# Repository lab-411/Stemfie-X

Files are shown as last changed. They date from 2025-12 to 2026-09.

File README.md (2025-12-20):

# Stemfie-X

STEMFIE-X je konštrukčná stavebnica zameraná na polytechnické vzdelávanie s podporou praktického osvojenia si skúseností z moderných technológií v oblasti návrhu a konštrukcie mechatronických systémov, konštrukčných materiálov, elektroniky, programovania a riadenia.

STEMFIE-X is a construction kit focused on polytechnic education with the support of practical acquisition of experience from modern technologies in the field of design and construction of mechatronic systems, structural materials, electronics, programming and control.

# Kniha / Book

Renderovaná kniha je dostupná na URL

The rendered book is available at URL

https://lab-411.github.io/Stemfie-X/_build/html/index.html

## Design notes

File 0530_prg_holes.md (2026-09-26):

---
jupytext:
  formats: md:myst
  text_representation:
    extension: .md
    format_name: myst
    format_version: 0.13
    jupytext_version: 1.11.5
kernelspec:
  display_name: Python 3
  language: python
  name: python3
---
# <font color='navy'> Montážne otvory  </font>

```{figure} ./img/banner.png
:width: 800px
:name: holes_201
```

Pre vytváranie montážnych dier, štrbín a drážok je v *Stemfie-X* vytvorená trieda *Hole*. Táto generuje pomocné objekty, ktoré sú potom od vopred vytvorených dielov odčítané pomocou logickéj operácie *Difference* `D()`. Štrbinu využívame aj pri konštrukciách, kde pri dieloch pod uhlom sa montážny otvor nenachádza v rastri **BU**. Princíp tvorby otvorov je zrejmý z nasledujúceho obrázku.

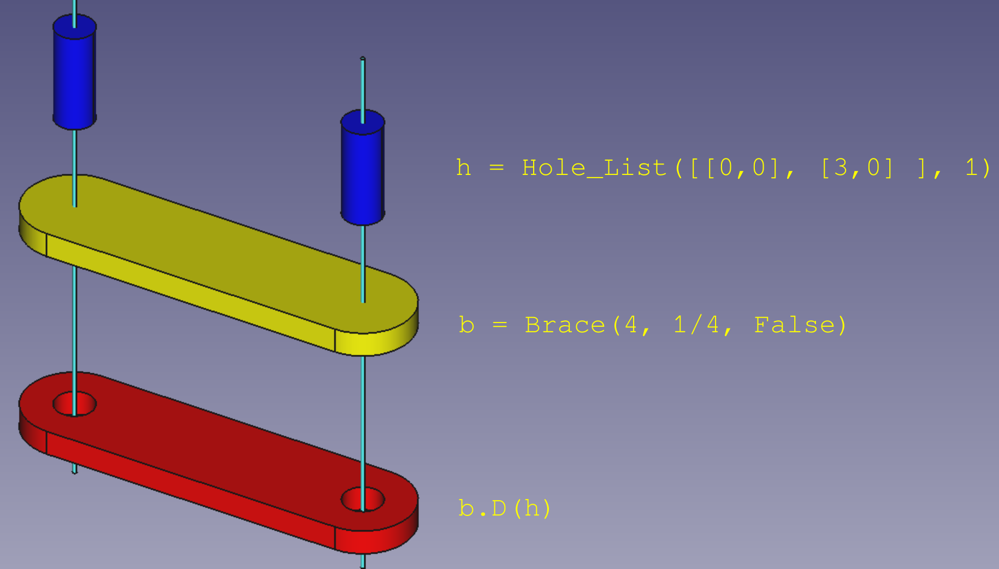
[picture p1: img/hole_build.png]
```{figure} ./img/hole_build.png
:width: 500px
:name: holes_202

Postup vytvárania otvorov v dieloch,
```

## <font color='purple'> Knižnica </font>

    Hole(length)
    Hole_List(hole_list, length)
    Hole_Grid(dim_x, dim_y, length, offs_x, offs_y, offs_z)
    Hole_Slot(size, height, center)
    
    Parametre       Default   Popis 
    --------------------------------------------------------------
    length          1         dĺžka diery v BU
    hole_list                 zoznam pozícií dier v BU [[x1,y1], [x2,y2] ... ]
    dim_x, dim_y              rozmery pola dier v BU
    offs_x          1         posun pola dier v smere osi X v BU 
    offs_y          1         posun pola dier v smere osi Y v BU 
    offs_z          1         posun pola dier v smere osi Z v BU 
    size                      dĺžka štrbiny v BU
    height          1/4       výška štrbiny v BU
    center          False     umiestnenie štrbiny v strede sur. sustavy
            
### <font color='brown'> Príklady použitia </font>

```{code-block} Python
:caption: Jednoduchá spojka so štrbinou
from lib import *
bs = Brace(5, holes=False)          # brace without holes
hh = Hole_Slot(3)                   # slot
hs = Hole_List([ [3,0], [4,0]] )    # holes
bs.D([hh, hs])                      # difference 
```

```{code-cell} ipython3  
:tags: ["remove-cell"]
from lib import *
                                    # Brace with slot and holes
bs = Brace(5, holes=False)          # brace without holes
hh = Hole_Slot(3)                   # slot
hs = Hole_List([ [3,0], [4,0]] )    # holes
bs.D([hh, hs])                      # difference 
convert_to_image(bs, './src/0520a')
```

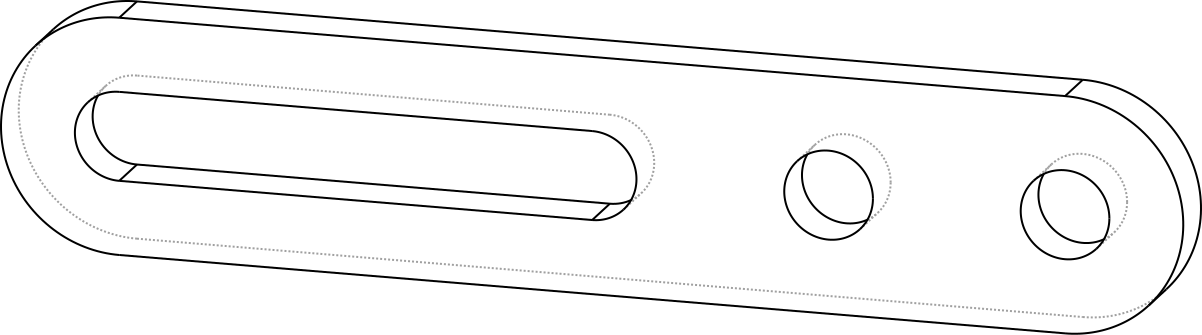
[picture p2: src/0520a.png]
```{figure} ./src/0520a.png
:width: 200px

jednoduchá spojka so štrbinou
```

```{code-block} Python
:caption: Použitie poľa otvorov
from lib import *
c = BU_Cube([4,4,1/4], False)
h = Hole_Grid( 4,2 , 1, 1/2, 1/2)
c.D(h)
```

```{code-cell} ipython3 
:tags: ["remove-cell"]
from lib import *
c = BU_Cube([4,4,1/4], False)
h = Hole_Grid( 4,2 , 1, 1/2, 1/2)
c.D(h)
convert_to_image(c, './src/0520c')
```

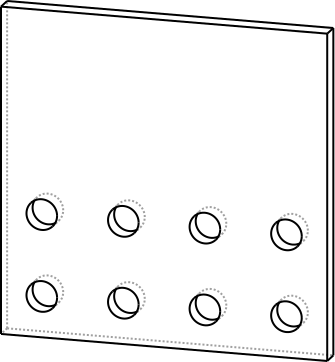
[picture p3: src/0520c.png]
```{figure} ./src/0520c.png
:width: 150px
Blok s otvormi.
```

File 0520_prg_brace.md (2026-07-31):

---
jupytext:
  formats: md:myst
  text_representation:
    extension: .md
    format_name: myst
    format_version: 0.13
    jupytext_version: 1.11.5
kernelspec:
  display_name: Python 3
  language: python
  name: python3
---

# <font color='navy'>  Spojky  </font>

```{figure} ./img/banner.png
:width: 800px
:name: stmx_112
```

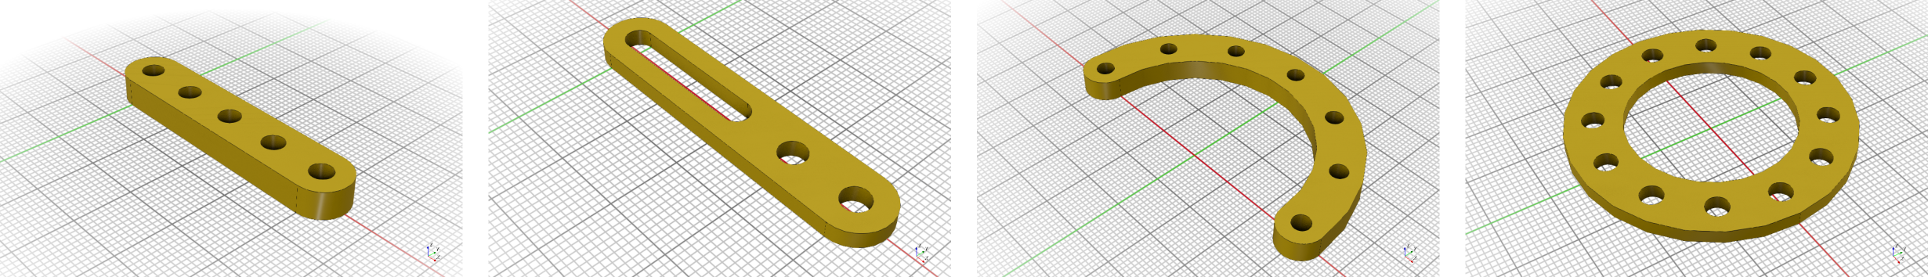
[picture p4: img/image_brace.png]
```{figure} ./img/image_brace.png
:width: 800px
:name: stmx_110

```

**Spojky** (Brace) sú základným konštrukčným typom dielov v *Stemfie-X* primárne určený pre spájanie dielov, ale je možné ich využiť aj ako konštrukčný prvok na vytváranie vystužených konštrukcií ako sú ramená žeriavov, robotov a pod. Spojky môžu obsahovať montážne otvory ako aj štrbiny. Štandardná hrúbka spojky je 1/4 **BU** (2.5mm), pomocou knižnice je možné programovo vytvárať spojky rôznych tvarov a konfigurácií. Lineárna spojka je rozmerovo kompatibilná s kovovými spojkami stavebníc *Meccano* a *Merkur* so vzdialenosťami montážnych otvorov 10mm. 

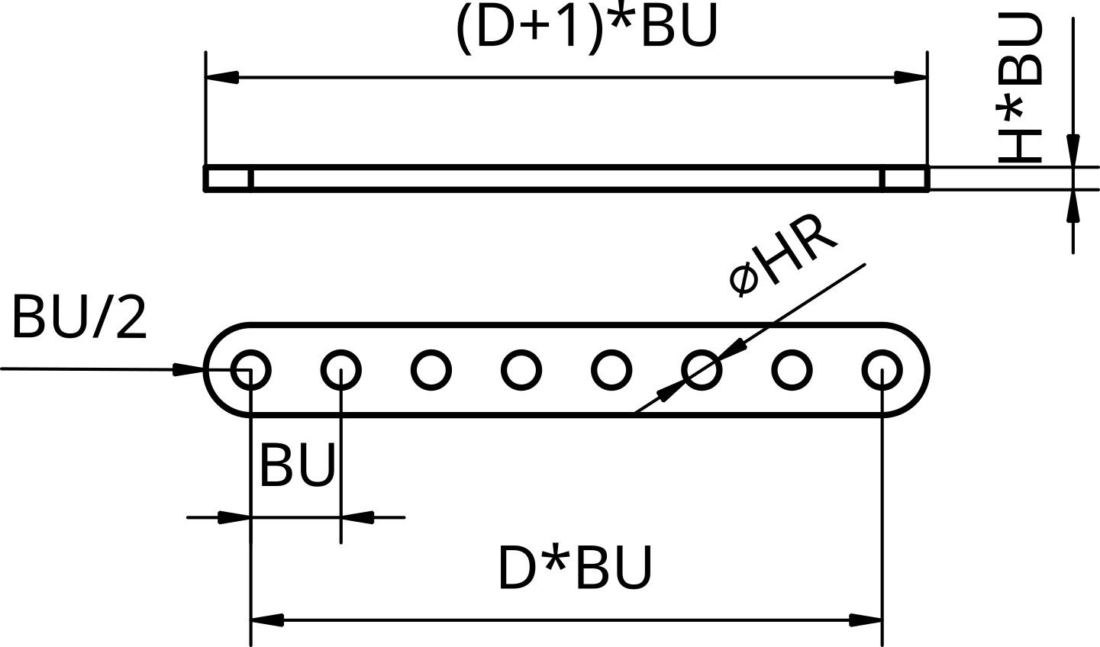
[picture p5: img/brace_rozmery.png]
```{figure} ./img/brace_rozmery.png
:width: 400px

Základné parametre spojky (spojka, D=8, H=1/4).
```

## <font color='purple'> Knižnica </font>

Pomocou knižnice môžeme vytvárať záladné typy spojok a pomocou logických operácií aj odvodené modifikácie. Základným typom je lineárna spojka *Brace*, oblúková spojka *Brace_Arc*, kruhová spojka *Brace_Circle* a rozšírená spjka *Brace_Plate*. Funkcie pre generovanie spojok majú formát:

    Brace(size, height, holes, center, hole_rad)
    Brace_Arc(radius, angle, height, num_holes, center, hole_rad)
    Brace_Circle(radius, height, num_holes, center, hole_rad)
    Brace_Plate(x, y,  height, holes, center, hole_rad)
    
    Parametre       Default   Popis 
    --------------------------------------------------------------
    size            1         rozmery v počte otvorov 
    height          1         výška
    length          1         dĺžka 
    radius          5         polomer
    holes           True      lineárna spojka / platňa s otvormi / bez otvorov
    num_holes       4         počet montážnych otvorov
    angle           180       uhol v stupňoch
    center          True      poloha v strede súradnicovej sústavy
    x               3         rozmer v smere osi X
    y               3         rozmer v smere osi Y
    hole_rad        HR_BASE   polomer všetkých otvorov (HR_BASE, HR_AXIS) alebo v BU

### <font color='brown'> Značenie dielov </font>

Pre prehľadnejšie označovanie spojok v zoznamoch dielov a katalógoch je vhodné tieto označovať kódmi, ktoré označujú ich parametre. Mená štandardných spojok sú generované automaticky pri ich vytváraní.

    brace_t_dd_hh_pp_ss[s]    basic form
    brace_t_dd_hh_pp          abbreviated forms, unlisted parameters have default values
    brace_t_dd_hh
    brace_t_dd

    t  - brace type                         dd - brace size               hh - brace height
         B - simple brace                        01 ... 99 BU                  01 =    1 BU
         C - circle brace                                                      ...
         A - arc brace                                                         10 =   10 BU
         P - brace plate                                                       12 =  1/2 BU
         X - user defined non standard brace                                   14 =  1/4 BU 

    ss - number of slots                    pp - number of holes if it does not match the size
         00 ... 99                               00 ... 99

    brace_B_dd_hh_pp_ss
        dd - brace size
        pp - number of holes
        ss - number of slots 
        
    brace_C_dd_hh_pp_ss
        dd - brace radius
        hh - brace height     
        pp - number of holes
        ss - number of slots (TODO, not implemented)

    brace_A_dd_hh_pp_sss
        dd  - brace radius
        hh  - brace height, default value is 1/4 BU      
        pp  - number of holes
        sss - brace angle in [deg] 001 ... 180
        
    brace_P_xx_yy_hh
        xx  - brace plate x size
        yy  - brace plate y size
        hh  - brace plate height, default value is 1/4 BU 

## <font color='purple'>  Príklady použitia </font>

### <font color='brown'> Jednoduchá spojka </font>

Pre vygenerovanie jednoduchej spojky o štandardnej hrúbke **1/4 BU** je postačujúce zadať jej rozmer v **BU** jednotkách.

```{code-block} Python
:caption: Vytvorenie jednoduchej spojky
from lib import *
b1 = Brace(5)               # brace_B_05_14
b1.export_step(b1.name)     # export spojky vo formate step  
```

```{code-cell} ipython3  
:tags: ["remove-cell"]

from lib import *
from lib.utils import *

b1 = Brace(5)    # brace_B_05
convert_to_image(b1, './src/brace_b1')
```

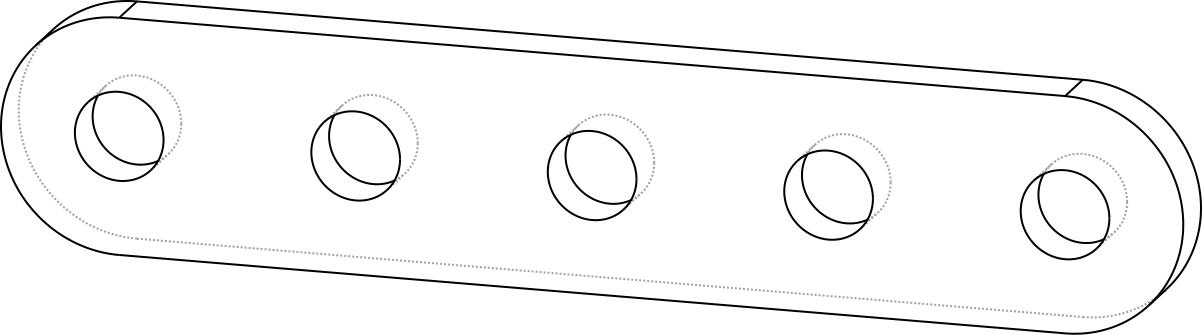
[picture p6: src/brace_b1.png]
```{figure} ./src/brace_b1.png
:width: 200px

Jednoducha spojka
```

### <font color='brown'> Spojka so štrbinami </font>

Štrbiny požadovanej dĺžky vytvoríme pomocou triedy **Hole_Slot**, posunieme ich pomocou operátora **BU_Tx** do požadovanej pozície a pomocou operátora **D()** odpočítame od štandardnej spojky.

```{code-block} Python
:caption: Vytvorenie spojky so štrbinami
from lib import *
b2 = Brace(17)              # standardna spojka
h1 = Hole_Slot(2).BU_Tx(4)  # strbina a jej posun dpo vzdialenosti BU=4
h2 = h1.copy().BU_Tx(7)     # kopia strbiny a posun o dalsich 7 BU

b2.D([h1, h2])              # odpocitanie strbin od zakladnej spojky
                            # export spojky - dlzka 17 otvorov, hrubka 1/4 BU, 
                            #                 13 otvorov, 2 strbiny 
b2.export_step('brace_B_17_14_13_02')
```

```{code-cell} ipython3  
:tags: ["remove-cell"]
from lib import *
from lib.utils import *
       
b2 = Brace(17)              # standardna spojka
h1 = Hole_Slot(2).BU_Tx(4)  # strbina a jej posun dpo vzdialenosti BU=4
h2 = h1.copy().BU_Tx(7)     # kopia strbiny a posun o dalsich 7 BU

b2.D([h1, h2])              # odpocitanie strbin od zakladnej spojky

convert_to_image(b2, './src/brace_b2')
```

```{figure} ./src/brace_b2.png
:width: 600px

Spojka so štrbinami.
```

### <font color='brown'> Uhlová spojka </font>

Uhlovú spojku vytvoríme operáciou zjednotenia dvoch štandardných spojok.

```{code-block} Python
:caption: Vytvorenie uhlovej spojky
from lib import *
b3 = Brace(4)               # standardna spojka
b4 = Brace(3).Rz()          # spojka otocena o 90 stupnov
b3.U(b4)                    # zjednotenie
                            # export uzivatelsky definovanej spojky
b3.export_step('brace_X_03_04_14')
```

```{code-cell} ipython3  
:tags: ["remove-cell"]
from lib import *
from lib.utils import *
       
b3 = Brace(4)               # standardna spojka
b4 = Brace(3).Rz()          # spojka otocena o 90 stupnov
b3.U(b4)                    # zjednotenie
                            # export uzivatelsky definovanej spojky
                        
convert_to_image(b3, './src/brace_b3')
```

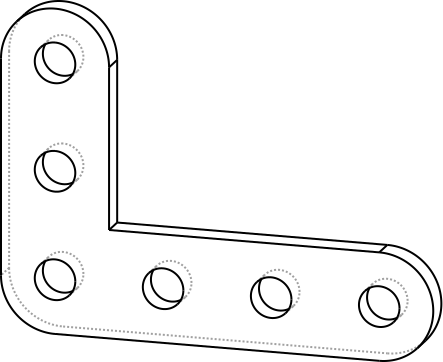
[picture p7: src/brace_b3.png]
```{figure} ./src/brace_b3.png
:width: 160px

Uživateľsky definovaná uhlová spojka.
```

### <font color='brown'> Oblúková spojka s tetivou </font>

Pri oblúkovej spojke musí mať tetiva oblúku veľkosť v násobkoch **BU**. Pre výpočet parametrov oblúkovej spojky zadáme dĺžku tetivy a polomer oblúka, napríklad

* radius = 4 BU
* brace length = 7 BU

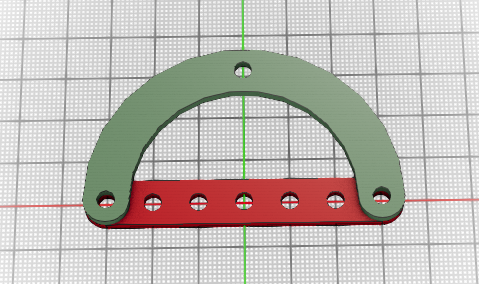
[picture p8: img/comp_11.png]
```{figure} ./img/comp_11.png
:width: 400px

Oblúková a lineárna spojka
```

Z uvedených parametrov musíme pre konštrukciu spojky výpočítať uhol a offsetu voči stredu opísanej kružnice podľa obrázku

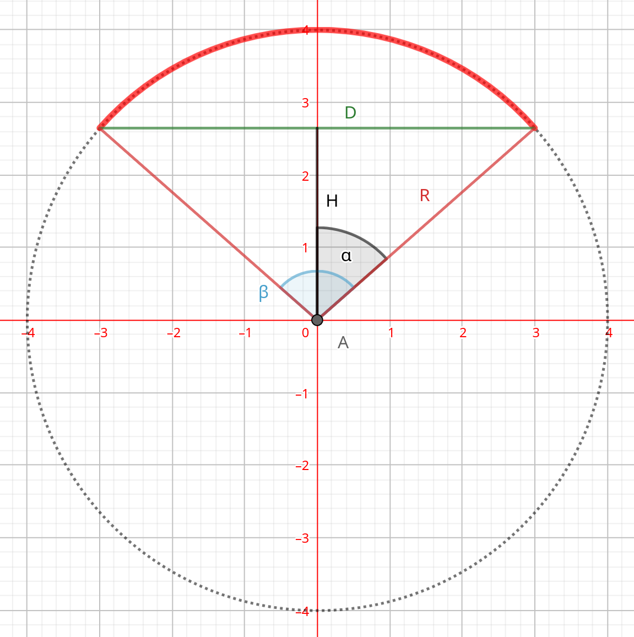
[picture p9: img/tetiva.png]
```{figure} ./img/tetiva.png
:width: 350px

Veličiny pre výpočet oblúkovej spojky
```

Vstupnými hodnotami pre výpočet sú

* $R$    - circle radius, in BU units
* $D$    - chord length in BU units, D >= 2*R+1

Výstupnými hodnotami sú 

* $\beta$ - calculated angle
* $H$    - calculated offset

$$
\begin{align*}
\beta &= 2 \alpha      \\
\frac{D-1}{2} &= R \cdot \sin(\alpha)    \\
\\
\beta &= 2 \alpha = 2 \cdot \arcsin \Big( \frac{D}{2R} \Big) \\
H &= R \cdot cos(\alpha) \\
\end{align*}
$$

Konštrukcia oblúkovej spojky na základe výpočtu

    from numpy import arcsin, pi

    R = 3   # arc radius
    D = 7   # D >= 2*R+1 
    N = 3   # pocet otvorov
    
    alpha = arcsin( (D-1) / (2*R ) )
    beta = 2*alpha/pi*180
    H = R*cos(alpha)

    b3 = Brace_Arc(R, bdeg, 1/4, N, center=True).Rz(90-bdeg/2).BU_T([0, -H, 0])
    b4 = Brace(D, center=True).BU_Tz(-1/2)

```{code-cell} ipython3  
:tags: ["remove-cell"]
from lib import *
from lib.utils import *
from numpy import arcsin, pi

D = 7   # D >= 2*R+1  
R = 3   # arc radius

alpha = arcsin( (D-1) / (2*R ) )
beta = 2*alpha/pi*180
H = R*cos(alpha)

b5 = Brace_Arc(R, beta, 1/4, 3, center=True).Rz(90-beta/2).BU_T([0, -H, 0])
b6 = Brace(D, center=True)  #.BU_Tz(-1/2)

b5.U(b6)
convert_to_image(b5, './src/brace_b5')
```

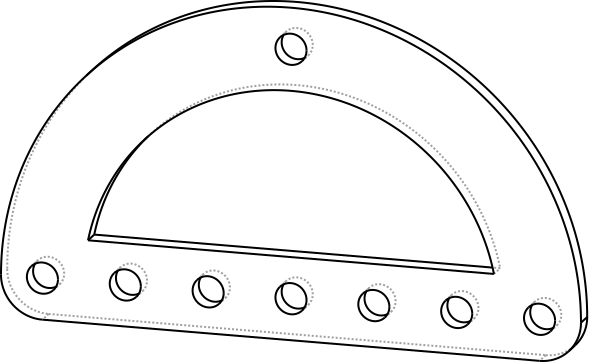
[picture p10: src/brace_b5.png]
```{figure} ./src/brace_b5.png
:width: 250px

Oblukova spojka s tetivou.
```

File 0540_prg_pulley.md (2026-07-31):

---
jupytext:
  formats: md:myst
  text_representation:
    extension: .md
    format_name: myst
    format_version: 0.13
    jupytext_version: 1.11.5
kernelspec:
  display_name: Python 3
  language: python
  name: python3
---
# <font color='navy'>  Kladky  </font>

```{figure} ./img/banner.png
:width: 800px
:name: stmx_112
```

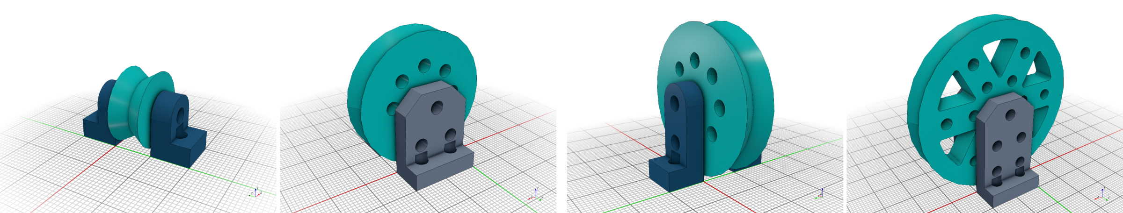
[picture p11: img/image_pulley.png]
```{figure} ./img/image_pulley.png
:width: 800px
:name: stmx_110

```

Kladky sú konštrukčnými prvkami pre tvorbu jednoduchých strojov (jednoduchá kladka, kladkostroj) a lanových prevodov.  

## <font color='purple'> Knižnica </font>

Knižnica obsahuje základné veľkosti kladiek a držiakov.

    Pulley_A(diam, thick, dp)
    Pulley_B(diam, thick, dp, dh, rh)
    Pulley_C(diam, thick, dp, dh, rh)
    
    Parametre       Default   Popis 
    --------------------------------------------------------------
    diam                      priemer kladky
    thick           1         hrubka kladky
    dp              1/2       zahlbenie kladky (vnutorny priemer)
    dh              1/4       hrubka nosnej vyplne kladky
    rh              [1]       pole priemerov otvorov
    
    Pulley_Holder_A(height)   držiak o šírke 1BU
    Pulley_Holder_B(height)   držiak o šírke 2BU

### <font color='brown'>  Značenie dielov </font>

    pulley_t_dd_hh

    t  - typ kladky
         A - jednoduchá plná kladka pre menšie priemery 
         B - odľahčená kladka pre väčšie priemery
         C - odľahčená kladka s lúčmi pre veľke priemery
    
    dd - priemer hladky
    hh - hrubka kladky
    
    pulhold_t_nn
    
    t  - typ držiaka
    hh - výška držiaka
    
## <font color='purple'> Príklady použitia </font>

    p0 = Pulley_A(2,1)        # pulley_A_02_01

```{code-cell} ipython3  
:tags: ["remove-cell"]

from lib import *
from lib.utils import *

p0 = Pulley_A(2,1)
convert_to_image(p0, './src/img_0540a')
```

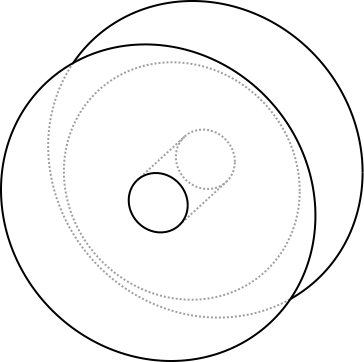
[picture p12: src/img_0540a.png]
```{figure} ./src/img_0540a.png
:width: 110px

Jednoducha plná kladka
```

    p1 = Pulley_B(3,1)        # pulley_B_03_01

```{code-cell} ipython3  
:tags: ["remove-cell"]

from lib import *
from lib.utils import *

p1 = Pulley_B(3,1)
convert_to_image(p1, './src/img_0540b')
```

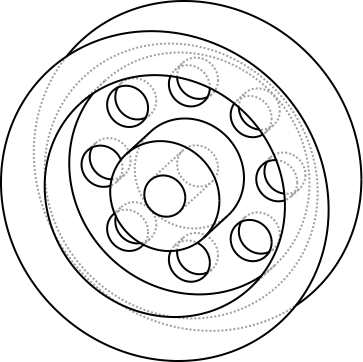
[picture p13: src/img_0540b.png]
```{figure} ./src/img_0540b.png
:width: 160px

Odľahčená kladka
```

    p1 = Pulley_B(3,1)        # pulley_B_03_01

```{code-cell} ipython3  
:tags: ["remove-cell"]

from lib import *
from lib.utils import *

p2 = Pulley_C(4,1)
convert_to_image(p2, './src/img_0540c')
```

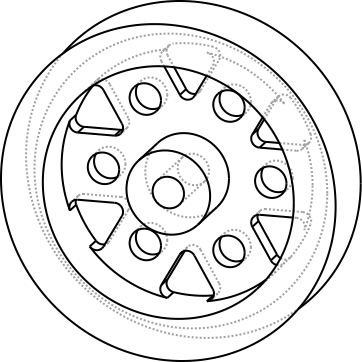
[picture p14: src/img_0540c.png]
```{figure} ./src/img_0540c.png
:width: 180px

Odľahčená veľká kladka
```

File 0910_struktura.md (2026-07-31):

---
jupytext:
  formats: md:myst
  text_representation:
    extension: .md
    format_name: myst
    format_version: 0.13
    jupytext_version: 1.11.5
kernelspec:
  display_name: Python 3
  language: python
  name: python3
---
# <font color='navy'>  Štruktúra knižnice  </font>

Knižnica je tvorená hierarchiou tried odvodenej z knižnica *CadQuery*. Pre tvorbu špeciálnych komponentov je možné triedy knižnice rozšírovať dedením a pridávaním ďalších špecifických vlastností. Štruktúru knižnice *Stemfie-X* zobrazuje nasledujúci diagram

```{code-cell} ipython3  
:tags: ["remove-cell"]

s = r'''
@startuml
hide footbox
scale 2

class Assembly #Khaki
class Workplane #Khaki

Assembly  --o Construct
Construct -> "Stemfie-X"
Workplane --o "Stemfie-X"  

"Stemfie-X" <|-- "Beam_Block"
"Stemfie-X" <|--- "Braces"
"Stemfie-X" <|--- "Holes"
"Stemfie-X" <|---- "BU_Components"

"BU_Components" <|-- "BU_Cube"
"BU_Components" <|-- "BU_Cylinder"
"BU_Components" <|-- "BU_Polyline"
"BU_Components" <|-- "BU_Bar"

"Holes" <|-- "Hole"
"Holes" <|-- "Hole_List"
"Holes" <|-- "Hole_Grid"
"Holes" <|-- "Hole_Slot"

"Braces" <|-- "Brace"
"Braces" <|-- "Brace_Arc"
"Braces" <|-- "Brace_Circle"

class "Stemfie-X" {
BU 
HR
self.obj
BU_Tx() BU_Tx() BU_Tz()
BU_Txy() BU_T() T()
Rx() Ry() Rz() 
Mx() Mx() Mz()
MKx() MKy() MKz() 
D()
U()
I()
copy()
}

class "Construct" {
self.name
self.obj
}

class Holes{
self.length
}

@enduml
'''

fp = open('./jar/prg_101.pnl', 'w')
fp.write(s)
fp.close()

import os
_ = os.system("java -jar ./jar/plantuml.jar ./jar/prg_101.pnl") 

```

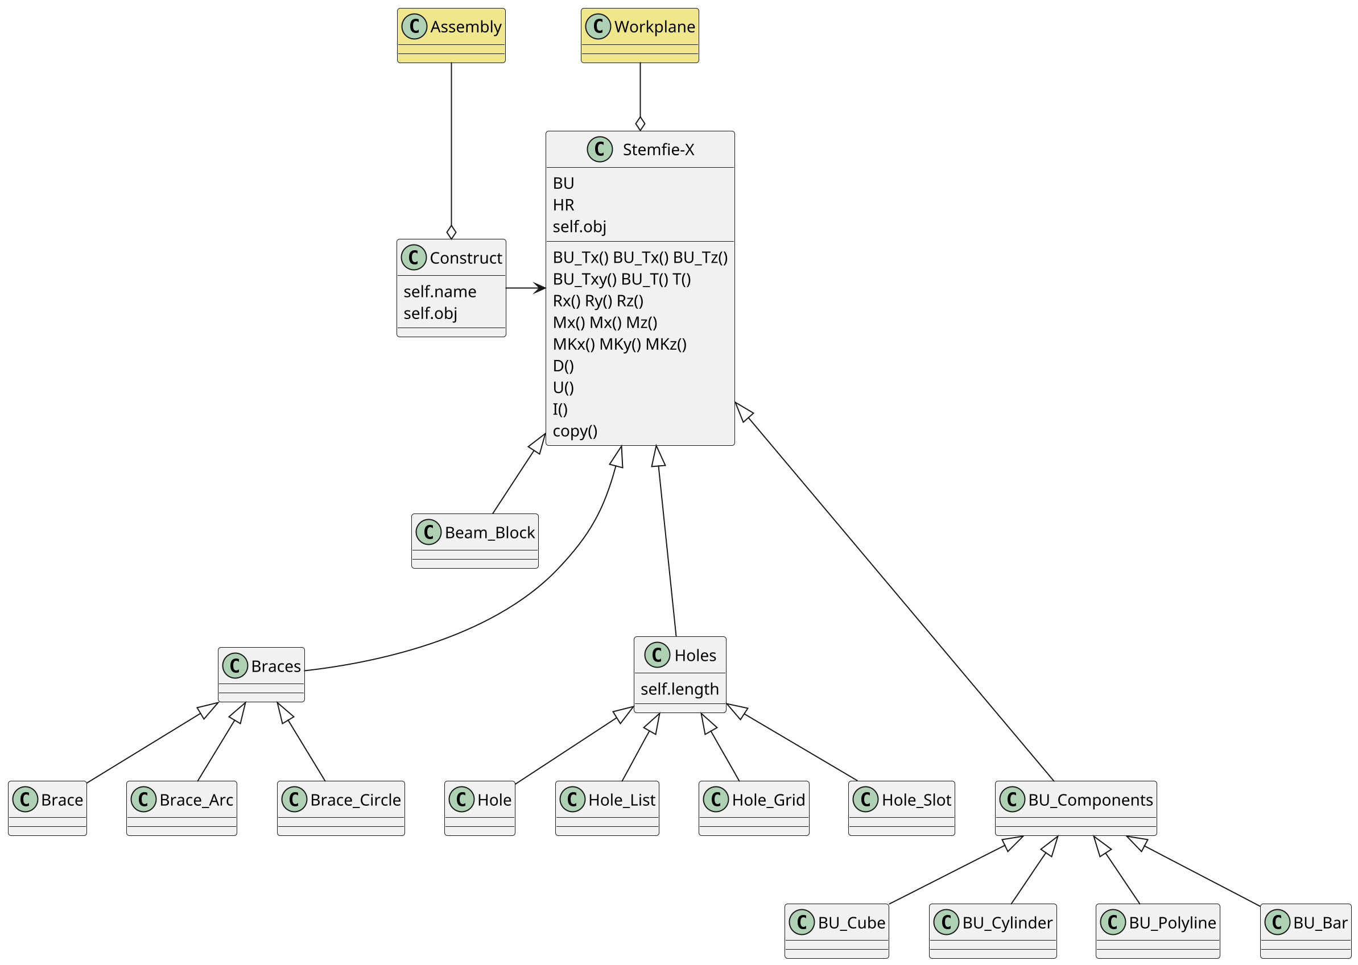
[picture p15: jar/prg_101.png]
```{figure} ./jar/prg_101.png
:width: 800px
:name: stm_0102

Štruktúra tried knižnice Stemfie-X 
```

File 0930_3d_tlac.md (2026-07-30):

---
jupytext:
  formats: md:myst
  text_representation:
    extension: .md
    format_name: myst
    format_version: 0.13
    jupytext_version: 1.11.5
kernelspec:
  display_name: Python 3
  language: python
  name: python3
---

# <font color='navy'> 3D Tlač  </font>

```{figure} ./img/banner.png
:width: 800px
```

## <font color='purple'> Export </font>

## <font color='purple'> Natavenie tlačiarne </font>

Doporučené parametre 3D tlače upravte podľa vašej tlačiarne a použitého materiálu. Diely stavebnice sú v tejto pulikácii generované vo formáte *.step* alebo *.stl*, pre ich tlač použite programové vybavenie doporučované výrobcom tlačiarne. V programe pre prípravu tlače (*slicer*) je vhodné nastaviť parametre tlače

* materiál PLA
* hrúbka vrstvy 0.2mm, bez podpier
* perimeter 4x
* výplň 15%
* teplota materiálu podľa doporučenia výrobcu filamentu, zvyčajne bližšie k hornej udávanej hranici

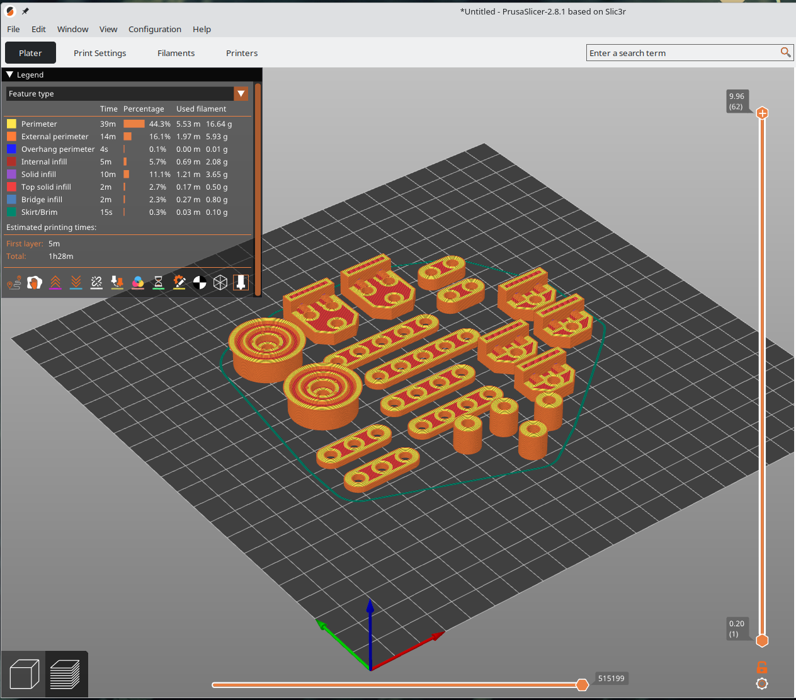
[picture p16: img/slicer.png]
```{figure} ./img/slicer.png
:width: 500px

Príprava tlače dielov stavebnice.
```

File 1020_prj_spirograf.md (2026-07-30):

---
jupytext:
  formats: md:myst
  text_representation:
    extension: .md
    format_name: myst
    format_version: 0.13
    jupytext_version: 1.11.5
kernelspec:
  display_name: Python 3
  language: python
  name: python3
---
# <font color='navy'> Spirograf  </font>

```{figure} ./img/banner.png
:width: 800px
```

```{figure} ./model/1020_spirograf/img/spirograf_demo.jpg
:width: 600px
```

S využitím knižnice pre návrh ozubených kolies možeme programom vytvoriť diely pre jednoduchý spirograf. Návrhom ozubených koles s rôznym počtom zubov môžeme dosiahnúť rôznu periódu pri ktorej sa budú krivky opakovať. 

## <font color='purple'> Návrh dielov </font>

### <font color='brown'> Základňa spirografu </font>

```{code-cell} ipython3  
from lib import *
from lib.utils import *
rg = Ring_Gear(90, 1/2, 1/4+1/8)
bs = BU_Cube([10, 10, 1/4]).BU_Tz(1/4/2)  
cc = BU_Cylinder(9+1/4,1, hole=False, center=True) 

ar = array([ [-4,-4], [-4,-3], [-3,-4],
              [5, 5], [ 5, 4], [ 4, 5], 
              [5,-4], [ 5,-3], [ 4,-4],
              [-4,5], [-4, 4], [-3, 5]]) -[1/2,1/2]

hh = Hole_List(ar)

bs.D([cc, hh])
bs.U([rg])
convert_to_image(bs, './src/sp_base_90')

#bs.export_step('sp_base_90')
```

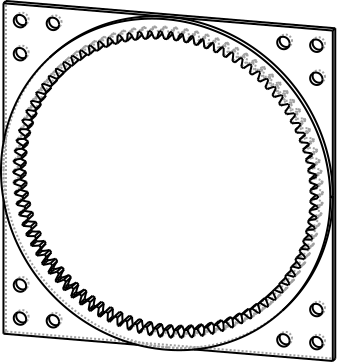
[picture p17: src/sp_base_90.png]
```{figure} ./src/sp_base_90.png
:width: 250px

Základňa spirografu
```

### <font color='brown'> Ozubené kolesá </font>

```{code-cell} ipython3  
sg = Spur_Gear(50, bore=2.5)
c2 = BU_Cylinder(4+1/2, 1/2, hole=False, center=True).BU_Tz(1/2) 
sg.D(c2)

dp = 60/180*pi
arr = []
for i in range(6,22):
    x = (i*0.092)*cos(i*dp)
    y = (i*0.092)*sin(i*dp)
    arr.append( BU_Cylinder(.25, 1, hole=False, center=True).BU_Txy(x,y) )

for i in range(6):
    x = (1.55)*cos(i*dp + pi/6)
    y = (1.55)*sin(i*dp + pi/6)
    arr.append( BU_Cylinder(1, 1, hole=False, center=True).BU_Txy(x,y) )   

sg.D(arr)
convert_to_image(sg, './src/sp_gear_50')

#sg.export_step('sp_gear_50')
```

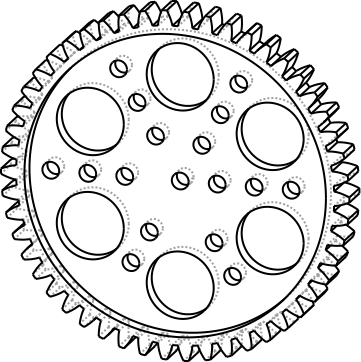
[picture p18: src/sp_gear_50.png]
```{figure} ./src/sp_gear_50.png
:width: 150px

Ozubené koleso, 50 zubov
```

```{code-cell} ipython3  
sg = Spur_Gear(40, bore=2.5)
c2 = BU_Cylinder(3+2/4, 1/2, hole=False, center=True).BU_Tz(1/2) 
sg.D(c2)

dp = 60/180*pi
arr = []
for i in range(6,22):
    x = (i*0.07)*cos(i*dp)
    y = (i*0.07)*sin(i*dp)
    arr.append( BU_Cylinder(.25, 1, hole=False, center=True).BU_Txy(x,y) )

for i in range(6):
    x = (1.22)*cos(i*dp + pi/6)
    y = (1.22)*sin(i*dp + pi/6)
    arr.append( BU_Cylinder(0.8, 1, hole=False, center=True).BU_Txy(x,y) )   

sg.D(arr)
convert_to_image(sg, './src/sp_gear_40')

#sg.export_step('sp_gear_40')
```

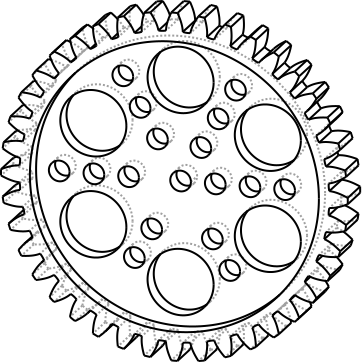
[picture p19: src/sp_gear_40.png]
```{figure} ./src/sp_gear_40.png
:width: 150px

Ozubené koleso, 40 zubov
```

```{code-cell} ipython3  
sg = Spur_Gear(65, bore=2.5)
c2 = BU_Cylinder(5+1/2+1/8, 1/2, hole=False, center=True).BU_Tz(1/2) 
sg.D(c2)

dp = 60/180*pi
arr = []
for i in range(6,22):
    x = (i*0.12)*cos(i*dp)
    y = (i*0.12)*sin(i*dp)
    arr.append( BU_Cylinder(.25, 1, hole=False, center=True).BU_Txy(x,y) )

for i in range(6):
    x = (1.9)*cos(i*dp + pi/6)
    y = (1.9)*sin(i*dp + pi/6)
    arr.append( BU_Cylinder(1.4, 1, hole=False, center=True).BU_Txy(x,y) )   

sg.D(arr)
convert_to_image(sg, './src/sp_gear_65')

#sg.export_step('sp_gear_65')
```

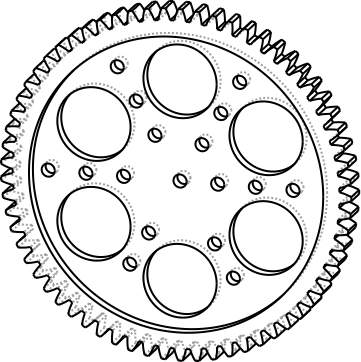
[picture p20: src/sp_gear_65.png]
```{figure} ./src/sp_gear_65.png
:width: 180px

Ozubené koleso, 65 zubov
```

## <font color='purple'> <b> Diely </b></font>

```{list-table}
:header-rows: 1

* - Počet
  - Popis
  - Farba
  - Súbor (step)
* - 1
  - Základňa spirografu, 90 zubov
  - modrá
  - [sp_base_90](./model/1020_spirograf/parts/sp_base_90.step)
* - 1
  - Ozubené koleso, 40 zubov
  - modrá
  - [sp_gear_40](./model/1020_spirograf/parts/sp_gear_40.step)
* - 1
  - Ozubené koleso, 50 zubov
  - modrá
  - [sp_gear_50](./model/1020_spirograf/parts/sp_gear_50.step)
* - 1
  - Ozubené koleso, 65 zubov
  - modrá
  - [sp_gear_65](./model/1020_spirograf/parts/sp_gear_65.step)
```

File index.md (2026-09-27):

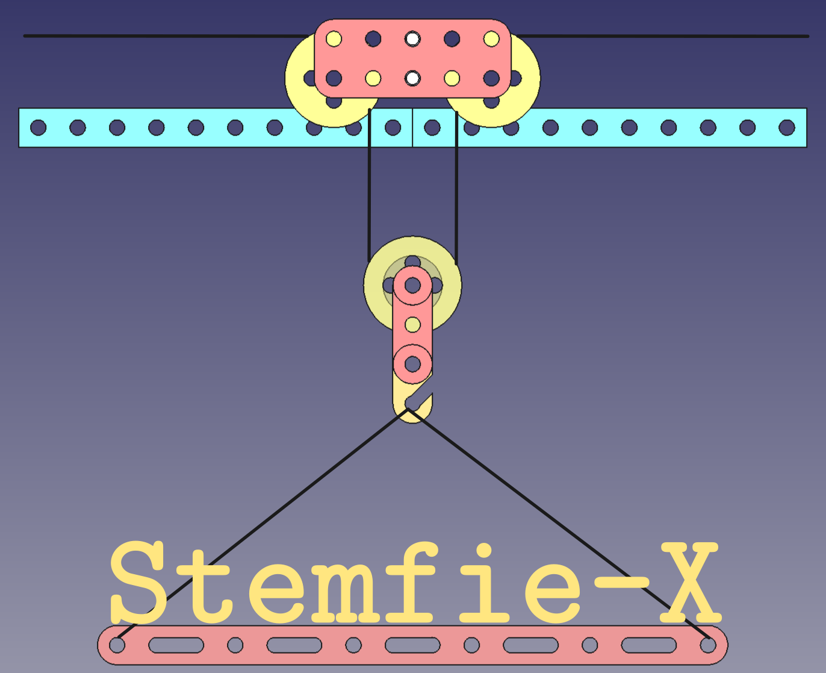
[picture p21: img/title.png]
```{figure} ./img/title.png
:width: 800px 
```
<center> 
<h3> <font color='brown'>  <b> Peter Fabo </b> </font> </h3>
<h3> <font color='brown'>  <b> LAB-411 Production </b> </font> </h3>
<h3> <font color='brown'>  <b> Verzia 0.18 / September 2026 </b> </font>                   </h3>
</center> 

# <font color='navy'>  Obsah </font>  

%```{contents} Table of Contents
%:depth: 2
%```

```{toctree}
:titlesonly: True
:caption: Úvod
0005_uvod.md
0007_prehlad.md
0015_montaz.md
```

```{toctree}
:titlesonly: True
:caption: Jednoduché konštrukcie
0210_exm_bridge.md
0220_exm_maly_mlyn.md
0215_exm_small_crane.md
0225_exm_maly_nakladac.md
```

%```{toctree}
%:titlesonly: True
%:caption: Knižnica komponentov
%0100_kniznica.md
%```

```{toctree}
:titlesonly: True
:caption: Vytváranie dielov
0500_prg_ako_na_to.md
0505_prg_lib.md
0520_prg_brace.md
0525_prg_beam.md
0540_prg_pulley.md
0550_prg_gears.md
0530_prg_holes.md
0535_prg_base.md
```

```{toctree}
:titlesonly: True
:caption: Projekty
1250_prj_bridge_waren.md
1020_prj_spirograf.md
```

```{toctree}
:titlesonly: True
:caption: Prílohy
0900_instalacia.md
0905_viewer.md
0910_struktura.md
0930_3d_tlac.md
0920_material.md
```

## <font color='purple'> Anotácia </font>   

Pracovná verzia publikácie.

## <font color='purple'> Vydavateľstvo </font> 

Vydalo vydavateľstvo *LAB-411 Production* v roku 2026.

**ISBN: xxx-xx-xxxxxx-x**

Publikované na platforme *Sphinx* s využitím jazyka *MyST Markdown*, programovacieho jazyka *Python* a knižnice *CadQuery*. Zdrojové kódy sú dostupné na 

    https://github.com/lab-411/Stemfie-X
    
## <font color='purple'> Preklady / Translations </font>

Preklady do iných jazykov sú možné v zmysle licencie MIT uvedenej nižšie. V zmysle nariadenia Európskeho parlamentu a Rady (EÚ) 2024/1689 z 13. júna 2024 autori tohoto diela **nepovolujú** využitie tohoto diela a ani jeho častí pre použitie v oblasti umelej inteligenice žiadnym aktuálnym ako aj budúcim spôsobom. 

Translations into other languages are possible under the terms of the MIT license listed below. In accordance with Regulation (EU) 2024/1689 of the European Parliament and of the Council of 13 June 2024, the authors of this work **do not** authorize the use of this work or any part of it for use in the field of artificial intelligence in any current or future manner.

## <font color='purple'> Citovanie publikácie </font>

## <font color='purple'>  Licencie a citácie zdrojov </font>   

Publikácia **Stemfie-X** je vydaná pod licenciou MIT

    Copyright © 2026 LAB-411 Team

    Permission is hereby granted, free of charge, to any person obtaining a copy 
    of this software and associated documentation files (the “Software”), to deal 
    in the Software without restriction, including without limitation the rights 
    to use, copy, modify, merge, publish, distribute, sublicense, and/or sell 
    copies of the Software, and to permit persons to whom the Software is furnished 
    to do so, subject to the following conditions:

    The above copyright notice and this permission notice shall be included in all 
    copies or substantial portions of the Software.

    THE SOFTWARE IS PROVIDED “AS IS”, WITHOUT WARRANTY OF ANY KIND, EXPRESS OR IMPLIED, 
    INCLUDING BUT NOT LIMITED TO THE WARRANTIES OF MERCHANTABILITY, FITNESS FOR 
    A PARTICULAR PURPOSE AND NONINFRINGEMENT. IN NO EVENT SHALL THE AUTHORS OR COPYRIGHT 
    HOLDERS BE LIABLE FOR ANY CLAIM, DAMAGES OR OTHER LIABILITY, WHETHER IN AN ACTION OF 
    CONTRACT, TORT OR OTHERWISE, ARISING FROM, OUT OF OR IN CONNECTION WITH THE SOFTWARE 
    OR THE USE OR OTHER DEALINGS IN THE SOFTWARE.
    
Licencia k **STEMFIE Construction Set**

    STEMFIE Licensing Terms
    https://stemfie.org/license

Licencia k distribúcii programu **Sphinx**

    Copyright (c) 2007-2025 by the Sphinx team (see AUTHORS file). All rights reserved.

    Redistribution and use in source and binary forms, with or without modification, 
    are permitted provided that the following conditions are met:

        Redistributions of source code must retain the above copyright notice, this list 
        of conditions and the following disclaimer.
        Redistributions in binary form must reproduce the above copyright notice, this list 
        of conditions and the following disclaimer in the documentation and/or other 
        materials provided with the distribution.

    THIS SOFTWARE IS PROVIDED BY THE COPYRIGHT HOLDERS AND CONTRIBUTORS "AS IS" AND ANY 
    EXPRESS OR IMPLIED WARRANTIES, INCLUDING, BUT NOT LIMITED TO, THE IMPLIED WARRANTIES 
    OF MERCHANTABILITY AND FITNESS FOR A PARTICULAR PURPOSE ARE DISCLAIMED. IN NO EVENT 
    SHALL THE COPYRIGHT HOLDER OR CONTRIBUTORS BE LIABLE FOR ANY DIRECT, INDIRECT, 
    INCIDENTAL, SPECIAL, EXEMPLARY, OR CONSEQUENTIAL DAMAGES (INCLUDING, BUT NOT LIMITED TO, 
    PROCUREMENT OF SUBSTITUTE GOODS OR SERVICES; LOSS OF USE, DATA, OR PROFITS; OR BUSINESS 
    INTERRUPTION) HOWEVER CAUSED AND ON ANY THEORY OF LIABILITY, WHETHER IN CONTRACT, STRICT 
    LIABILITY, OR TORT (INCLUDING NEGLIGENCE OR OTHERWISE) ARISING IN ANY WAY OUT OF 
    THE USE OF THIS SOFTWARE, EVEN IF ADVISED OF THE POSSIBILITY OF SUCH DAMAGE.

Citácia **MyST Markdown**

    Rowan Cockett, Franklin Koch, Steve Purves, Angus Hollands, Yuxi Wang, Chris Holdgraf, 
    Dylan Grandmont, Stefan van der Walt, Andrea, Jan-Hendrik Müller, Spencer Lyon, 
    Cristian Le, Jim Madge, Thierry Parmentelat, wwx, Sugan Reden, Yuanhao Geng, Ryan Lovett, 
    Mikkel Roald-Arbøl,Nicolas M. Thiéry. 
    (2025). jupyter-book/mystmd: mystmd@1.6.0. Zenodo. 10.5281/ZENODO.14805610

Citácia **CadQuery**

    CadQuery contributors. (2025). CadQuery (v2.6.1). Zenodo. 
    https://doi.org/10.5281/zenodo.14590990

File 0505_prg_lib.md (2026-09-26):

---
jupytext:
  formats: md:myst
  text_representation:
    extension: .md
    format_name: myst
    format_version: 0.13
    jupytext_version: 1.11.5
kernelspec:
  display_name: Python 3
  language: python
  name: python3
---
# <font color='navy'> Knižnica   </font>

```{figure} ./img/banner.png
:width: 800px
:name: prg_100
```

Pri návrhu vlastných konštrukcií často potrebujeme upraviť a modifikovať štandardné diely z katalógu alebo vytvárať nové diely podľa vlastného návrhu. Možnosť tvorby vlastných dielov a konštrukcií podľa vlastného návrhu je základnou ideou stavebnice *STEMFIE-X*. Návrh dielov sa vytvára pomocou skriptov v programovacom jazyku *Python* pomocou knižnice *STEMFIE-X*, ktorá obsahuje postupy pre tvorbu základných typov dielov a operácie pre ich manipuláciu. Komplikovanejšie diely sa vytvárajú zo základných typov pomocou ich modifikácií a úprav.   

## <font color='purple'> Vytváranie komponentov </font>

Knižnicu *STEMFIE-X* tvorí sada tried v programovacom jazyku *Python* implementovaná pomocou knižnice *[CadQuery](https://cadquery.readthedocs.io/en/latest/)*. Vlastné diely stavebnice je možné vytvárať programom jednoducho v jednom kroku volaním funkcií s parametrami dielov, nové diely je možné tvoriť z iných dielov pomocou jednoduchých logických operácií (prienik, rozdiel, zjednotenie). Pre vytváranie štandardných ako aj odvodených dielov stavebnice postačujú triedy knižnice *STEMFIE-X*, pokročílí uživatelia ale môžu využiť všetky možnosti knižnice *[CadQuery](https://cadquery.readthedocs.io/en/latest/)* a jazyka *Python*. 

Pre generovanie podkladov pre 3D tlač štandardných komponentov je potrebné v programe importovať knižnicu [lib](./lib/lib.zip) a vygenerovať želaný komponent vytvorením objektu danej triedy.

```{code-block} python
:caption: Vytvorenie komponentu stavebnice
from lib import *           # import kniznice
b1 = Brace(5)               # vytvorenie noveho komponentu - spojky o velkosti 5 BU
b1.export_step(b1.name)     # export spojky vo formate step pre 3D tlac
```

## <font color='purple'> Transformácie objektov </font>

Pri vytváraní nových komponentov stavebnice alebo tvorbe zostáv potrebujeme s objektami manipulovať v 3D priestore. Metódy triedy *Stemfie_X* pre manipuláciu s objektami sú zjednodušenou formou operácií z knižnice *CadQuery*. Všeobecný formát transformácií  má tvar

    object = object.operation( <param ...> )
    
    b1 = Brace(5)           # vytvoreny novy komponent
    b1.BU_Tx(3)             # operacia posunu - v smere osi X o vdialenost 3*BU

Každá transformáciu vracia referenciu na transformovaný objekt, takže je možné transformácie reťaziť

    object = object.operation_1(<param ...>).operation_2(<param>)  ... 
    
    b1.BU_Tz(1).Rx(45)      # posun a nasledna rotacia objektu
    
Operácie s prefixom *BU_* pracujú s jednotkami *BU*, bez prefixu s dĺžkovými jednotkami v mm alebo pri rotáciách v stupňoch.

### <font color='brown'> Operácie lineárneho posunu </font>

Posuny objektu v smeroch osí súradnicovej sústavy

    BU_Tx(n)                      # posun objektu v smere x,y,z v jednotkách BU 
    BU_Ty(n)
    BU_Tz(n)
    BU_Txy([x,y])  BU_Txy(x,y)    # posun v dvoch osiach v jednotkách BU
    BU_Tyz([x,y])  BU_Tyz(y,z)
    BU_Tzx([z,x])  BU_Tzx(z,x)
    
    BU_T([x,y,z])  BU_T(x,y,z)    # všeobecný posun v jednokách BU    
    
    Tx(d)                         # posun objektu v jednotkách [mm] 
    Ty(d)
    Tz(d)
    
    T([x,y,z])     T(x,y,z)      # všeobecný posun v [mm]

### <font color='brown'> Operácie rotácie </font>

Rotácie objektu okolo osí súradnicovej sústavy. Veľkosť uhla *angle* je v stupňoch.

    Rx(angle)
    Ry(angle)
    Rz(angle)

### <font color='brown'> Operácie zrkadlenia </font> 

V prípade potreby vytvárania symetrických objektov a konštrukcií môžeme využiť operácie zrkadlenie objektu podľa osí súradnicovej sústavy. Pri zrkadlení môžeme pôvodný objekt zachovať a vytvoriť jeho novú kópiu.

    Mx()       # zrkadlenie objektu
    My()
    Mz()
    
    MKx()      # zrkadlenie s kopírovaním
    MKy()
    MKz()  

### <font color='brown'>  Logické operácie </font>

Pre vytváranie zložených objektov sú definované základné logické operácie - zjednotenie (union), rozdiel (difference) a prienik (intersection). Výsledkom logickej operácie je objekt obsahujúci argument logickej operácie, napríklad výsledkom zjednotenia dvoch objektov je jeden objekt. Arguementom logických operácií môže byť jeden objekt alebo viacero objektov, ktoré sú položkami zoznamu.

    U(c)   U([c1,c2 ...])     union
    D(c)   D([c1,c2 ...])     difference
    I(c)   I([c1,c2 ...])     intersection  

````{admonition} Príklad použitia logických operácií  
:class: dropdown, note 

S využitím knižnice základných komponentov a transformačných metód môžeme vytvárať zložené objekty. Najskôr vytvoríme jednotlivé objekty, pomocou transformačných vzťahov ich posunieme do správnej pozícia a nakoniec ich logickou operáciou zjednotíme do finálneho zloženého objektu.

```{code-block} python
:caption: Použitie transformácií na vytvorenie zloženého objektu
                       
b1 = Brace(8, 1/4).BU_Tx(-(3+1/2))  # spojka v rovine XY a presun do stredu 
c1 = BU_Cylinder(1).BU_Tz(1/2+1/4)  # valec a presun nad spojku
c1=  c1.BU_Tx(3+1/2)                # presun valca na konec spojky
c2 = c1.MKy()                       # vytvorenie druheho valca 
                                    # zrkadlenim v osi Y s kopiou
b1.U([c1,c2])                       # zjednotenie objektov
b1.export_step('part_b1')           # export dielu
```

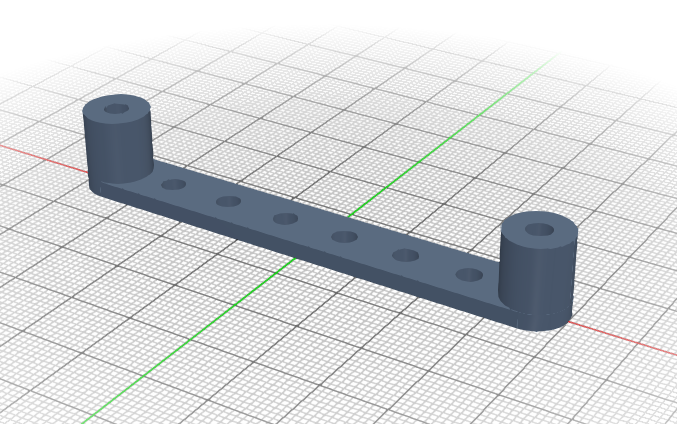
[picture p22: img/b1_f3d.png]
```{figure} ./img/b1_f3d.png
:width: 400px

Vygenerovaný zložený objekt.
```
````

## <font color='purple'> Export komponentov </font>

Export komponentov stavebnice do súborov typu *.step* alebo *.stl* pre generovanie podkladov pre 3D tlač je pomocou funkcií 

    object.export_step(file_name)   # export vo formate STEP  
    object.export_stl(file_name)    # export vo formate STL
    
        object    - vytvoreny komponent
        file_name - textový reťazec (string), bez prípony

Náhlad objektu vo formáte *.png* vygenerujeme pomocou funkcie 

    convert_to_image(object, file_name, ax, ay, az)
    
        object    - vytvoreny komponent
        file_name - meno grafického súboru, textový reťazec (string), bez prípony
        ax,ay,az  - poloha view-pointu pre náhlad na objekt
    
Nasledujúci programu ukazuje použitie funkcií pre export komponentov

```{code-block} python
:caption: Export objektov

from lib import *              # import kniznice
b1 = Brace(5)                  # vytvorenie komponentu
b1.export_step(b1.name)        # export komponentu s automaticky generovanym menom

convert_to_image(b1, b1,name)  # vyvorenie png obrazku s nahladom komponentu
```

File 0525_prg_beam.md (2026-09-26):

---
jupytext:
  formats: md:myst
  text_representation:
    extension: .md
    format_name: myst
    format_version: 0.13
    jupytext_version: 1.11.5
kernelspec:
  display_name: Python 3
  language: python
  name: python3
---
# <font color='navy'> Nosníky </font>

```{figure} ./img/banner.png
:width: 800px
:name: stmx_201
```

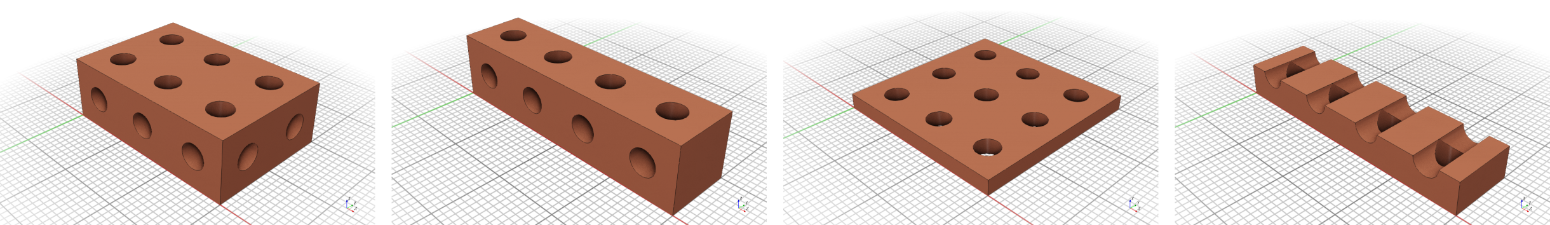
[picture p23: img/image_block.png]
```{figure} ./img/image_block.png
:width: 800px
:name: stmx_110

```

**Nosníky** (Baems) sú druhým základným typom dielov v *Stemfie-X* primárne určené pre použitie ako nosníky a platne. Verzie *U*, *L* a H je možné využiť ako základne pre menšie konštrukcie.

## <font color='purple'> Knižnica </font>

Základným typom je jednoduchy nosník (Beam_Block), odvodenými typmi sú verzie *U*, *H*, *L*. 

    Beam_Block([x,y,z], center)
    Beam_Block(d, center)
    Beam_U_Block(x,y)
    Beam_H_Block(x,y)
    Beam_L_Block(x,y)
    
    Parametre       Default   Popis 
    --------------------------------------------------------------
    d               1         rozmery v počte otvorov 
    x,y,z           1         rozmery
    center          True      poloha v strede súradnicovej sústavy 

### <font color='brown'> Značenie dielov </font>

    block_t_xx_yy_zz_hhh    basic form
    block_t_xx_yy           abbreviated forms
    block_t_xx

    t  - block type                               xx,yy,zz - block dimension
         B - simple beam                                     01 =   1 BU
         U - beam block modifications                        ...
         H                                                   10 =  10 BU
         L                                                   12 = 1/2 BU
         X - user defined non standard block                 14 = 1/4 BU 
        
    hhh - holes configuration in x y z directions
        000 - no holes
        100 - holes in x direction
        ...
        111 - holes in all directions

    block_B_xx_yy_zz_hhh
    block_H_xx_yy_hx_hy
    block_U_xx_yy_hx_hy
    block_L_xx_yy_hx_hy

## <font color='purple'>  Použitie  </font>     

### <font color='brown'> Jednoduché nosniky a bloky </font>

Pomocou parametrov funkcie *Beam_Block()* môžeme vytvárať rôzne typy nosníkov, blokov a platní.

```{code-block} Python
:caption: Jednoduchý nosník s montážnymi otvormi v xyz smeroch.
from lib import *
b1 = Beam_Block(7)  
b1.export_step(b1.name)
```

```{code-cell} ipython3  
:tags: ["remove-cell"]

from lib import *
from lib.utils import *

b0 = Beam_Block(7)
convert_to_image(b0, './src/block_b0')
```

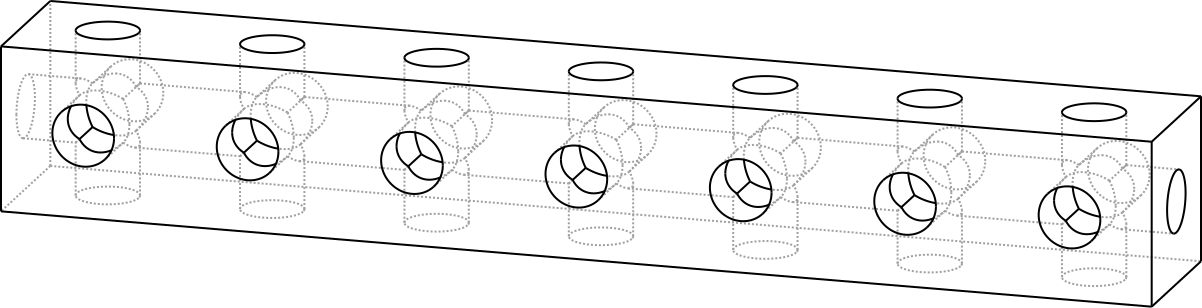
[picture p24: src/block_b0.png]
```{figure} ./src/block_b0.png
:width: 300px

Jednoduchý nosník.
```

%--------------------------------------------------

```{code-block} Python
:caption: Blok s redukovanými montážnymi otvormi.
from lib import *
b2 = Beam_Block([3, 3, 2], [False, True, True]) 
b2.export_step(b2.name)
```

```{code-cell} ipython3  
:tags: ["remove-cell"]

from lib import *
from lib.utils import *

b1 = Beam_Block([3, 3, 2], [False, True, True])
convert_to_image(b1, './src/block_b1')
```

```{figure} ./src/block_b1.png
:width: 150px

Blok s redukovanými montážnymi otvormi.
```

%--------------------------------------------------

```{code-block} Python
:caption: Montážna platňa 4x3 BU 
from lib import *
b3 = Beam_Block([4, 3 ,1/2], [False, False, True]) 
b3.export_step(b3.name)
```

```{code-cell} ipython3  
:tags: ["remove-cell"]

from lib import *
from lib.utils import *

b2 = Beam_Block([4,3,1/2], [False, False, True])  
convert_to_image(b2, './src/block_b2')
```

```{figure} ./src/block_b2.png
:width: 150px

Montážna platňa 4x3 BU 
```

### <font color='brown'> Kombinované nosniky </font>

Kombinované nosníky sú tuhšie ako jednoduché platne, môžeme ich použiť pri tvorbe väčších a namáhaných konštrukcií. 

```{code-block} Python
:caption: Blok typu U
from lib import *
b4 = Beam_U_Block(4,3)
b4.export_step(b4.name)
```

```{code-cell} ipython3  
:tags: ["remove-cell"]

from lib import *
from lib.utils import *

b4 = Beam_U_Block(4,3)  
convert_to_image(b4, './src/block_b4')
```

```{figure} ./src/block_b4.png
:width: 150px

Blok typu U
```
    
%--------------------------------------------------

```{code-block} Python
:caption: Blok typu H
from lib import *
b5 = Beam_H_Block(4,3) 
b5.export_step(b5.name)
```

```{code-cell} ipython3  
:tags: ["remove-cell"]

from lib import *
from lib.utils import *

b5 = Beam_H_Block(4,3) 
convert_to_image(b5, './src/block_b5')
```

```{figure} ./src/block_b5.png
:width: 150px

Blok typu H 
```

%--------------------------------------------------

```{code-block} Python
:caption: Blok typu L
from lib import *
b6 = Beam_L_Block(7,2,1/4, 1/2)
b6.export_step(b6.name)
```

```{code-cell} ipython3  
:tags: ["remove-cell"]

from lib import *
from lib.utils import *

b6 = Beam_L_Block(7,2,1/4, 1/2)
convert_to_image(b6, './src/block_b6')
```

```{figure} ./src/block_b6.png
:width: 220px

Blok typu L 
```

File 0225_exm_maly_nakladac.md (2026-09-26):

---
jupytext:
  formats: md:myst
  text_representation:
    extension: .md
    format_name: myst
    format_version: 0.13
    jupytext_version: 1.11.5
kernelspec:
  display_name: Python 3
  language: python
  name: python3
---
# <font color='navy'> Malý nakladač </font>

```{figure} ./img/banner.png
:width: 800px
:name: exam_001
```

Model je v príprave.

```{figure} ./model/0225_bobcat/img/img_01.png
:width: 400px

```

## <font color='purple'> Montáž </font>

```{figure} ./model/0225_bobcat/img/img_03.png
:width: 400px

```

```{figure} ./model/0225_bobcat/img/img_02.png
:width: 400px

```

## <font color='purple'> Diely </font>

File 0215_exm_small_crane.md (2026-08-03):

---
jupytext:
  formats: md:myst
  text_representation:
    extension: .md
    format_name: myst
    format_version: 0.13
    jupytext_version: 1.11.5
kernelspec:
  display_name: Python 3
  language: python
  name: python3
---
# <font color='navy'> Malý žeriav  </font>

```{figure} ./img/banner.png
:width: 800px
:name: exam_001
```

Model malého žeriavu umožňuje zdvíhanie bremena pomocou jednoduchej kladky a navijakom. V modeli sú použité rotačné spoje, rameno žeriavu je možné zdvihať a kabína sa môže otáčať. Model je určený pre mierne pokročilých staviteľov, v prípade potreby vyžaduje mierne úpravy otvorov pre hriadele a fixáciu otočných prvkov vhodným lepidlom. 

```{figure} ./model/0215_mini_zeriav/img/zeriav_01.jpg
:width: 500px

Malý žeriav.
```

## <font color='purple'> Montáž </font>

Model pozostáva z ramena, kabíny a podvozku. Samostatne zložíme rameno a podvozok, na podlahu kabíny upevníme rameno zospodu jednou skrutkou M4x5. Priskrutkujeme jednu stenu kabíny, nasadíme navijak, druhú stenu a strechu. Nasadíme a v prípade potreby fixujeme kľuku navijaku, doplníme povrázok a hák.  

### <font color='brown'> Rameno žeriavu </font>

Pre montážou kladku, podperu ramena a podstavu nasadeníme tesne na hriadele o dĺžke 16mm. Otvory v dieloch sú upravené pre požitie hriadeľov, samotné hriadele sa v nosníkoch ramena majú otáčať voľne. V prípade potreby upravte veľkosti otvorov v ramenách ihlovým pilníkom.  

````{subfigure} AB
:layout-sm: A|B
:gap: 2px
:subcaptions: below
:width: 700px

```{image} ./model/0215_mini_zeriav/img/diely_01.jpg
:alt: Diely ramena
:width: 300px
```

```{image} ./model/0215_mini_zeriav/img/rameno_03.png
:alt: Zostava ramena
:width: 300px
```
Konštrukcia ramena žeriavu.
````

````{dropdown} Diely ramena žeriavu.

```{list-table}
:header-rows: 1

* - Počet
  - Popis
  - Farba
  - Súbor (step)
* - 2
  - Rameno žeriavu
  - žltá
  - [brace_B_17_14](./model/0215_mini_zeriav/parts/brace_B_17_14.step)
* - 2
  - Spojka
  - červená
  - [brace_B_02_01](./model/0215_mini_zeriav/parts/brace_B_02_01.step)
* - 1
  - Kladka
  - oranžová
  - [pulley_A_15](./model/0215_mini_zeriav/parts/pulley_A_15.step)
* - 1
  - Podpera
  - oranžová
  - [podpera](./model/0215_mini_zeriav/parts/podpera.step)
* - 1
  - Podstava
  - červená
  - [rack_2](./model/0215_mini_zeriav/parts/rack_2.step)
* - 3
  - Hriadel 4x15mm
  - 
  - 
* - 8
  - Skrutka M4x8
  - 
  - 
```
````

### <font color='brown'> Podvozok </font>

Hriadele kolies by sa mali v bočniciach podvozku otáčať voľne, os pre otáčanie kabíny by mala byť tesne nasunutá do bloku pdovozku.

````{subfigure} AB
:layout-sm: A|B
:gap: 2px
:subcaptions: below
:width: 700px

```{image} ./model/0215_mini_zeriav/img/diely_03.jpg
:alt: Diely podvozku
:height: 200px
```

```{image} ./model/0215_mini_zeriav/img/podvozok_01.png
:alt: Zostava podvozku
:height: 200px
```

Konštrukcia podvozku žeriavu.
````

````{dropdown} Diely podvozku žeriavu.

```{list-table}
:header-rows: 1

* - Počet
  - Popis
  - Farba
  - Súbor (step)
* - 2
  - Bočnica
  - žltá
  - [brace_B_09_14](./model/0215_mini_zeriav/parts/brace_B_09_14.step)
* - 1
  - Blok predný
  - žltá
  - [block_B_03_01_01](./model/0215_mini_zeriav/parts/block_B_03_01_01.step)
* - 1
  - Blok zadný
  - žltá
  - [block_B_03_02_01](./model/0215_mini_zeriav/parts/block_B_03_02_01.step)
* - 4
  - Disk kolesa
  - červená
  - [tire_D_01_03_15](./model/0215_mini_zeriav/parts/tire_D_01_03_15.step)
* - 4
  - Pneumatika
  - čierna
  - [tire_T_01_03_15](./model/0215_mini_zeriav/parts/tire_T_01_03_15.step)
* - 2
  - Hriadel 4x50mm
  - 
  - 
* - 1
  - Hriadel 4x30mm
  - 
  - 
* - 6
  - Skrutka M4x8
  - 
  - 
```
````

### <font color='brown'> Kabína </font>

Pre upevnenie strechy kabíny sú použité skrutky M4x5, dlhšie krutky bu zasahovali do navijaku.

````{subfigure} AB
:layout-sm: A|B
:gap: 2px
:subcaptions: below
:width: 700px

```{image} ./model/0215_mini_zeriav/img/kabina_05.png
:alt: Zostava kabíny
:height: 200px
```

```{image} ./model/0215_mini_zeriav/img/navijak_01.png
:alt: Zostava navijaku
:height: 200px
```

Konštrukcia kabíny.
````

````{dropdown} Diely kabíny žeriavu.

```{list-table}
:header-rows: 1

* - Počet
  - Popis
  - Farba
  - Súbor (step)
* - 2
  - Bočnica kabíny
  - bledomodrá
  - [block_X_05_04](./model/0215_mini_zeriav/parts/block_X_05_04.step)
* - 1
  - Podlaha
  - šedá
  - [block_U_05_03](./model/0215_mini_zeriav/parts/block_U_05_03.step)
* - 1
  - Strecha
  - šedá
  - [block_U_02_03](./model/0215_mini_zeriav/parts/block_U_02_03.step)
* - 4
  - Skrutka M4x5
  - 
  - Upevnenie strechy
* - 4
  - Skrutka M4x8
  - 
  - Upevnenie podlahy
```
````

````{dropdown} Diely navijaka.

```{list-table}
:header-rows: 1

* - Počet
  - Popis
  - Farba
  - Súbor (step)
* - 2
  - Bočnica navijaka
  - žltá
  - [wheel_A_15_14](./model/0215_mini_zeriav/parts/wheel_A_15_14.step)
* - 1
  - Valec navijaka
  - žltá
  - [base_C_01_13](./model/0215_mini_zeriav/parts/base_C_01_13.step)
* - 1
  - Teleso kluky
  - zelená
  - [wheel_B_02_14](./model/0215_mini_zeriav/parts/wheel_B_02_14.step)
* - 1
  - Rúčka kluky
  - zelená
  - [base_C_01_15](./model/0215_mini_zeriav/parts/base_C_01_15.step)
* - 1
  - Hák
  - červená
  - [comp_C_hook_block_02](./model/0215_mini_zeriav/parts/comp_C_hook_block_02.step)
* - 1
  - Skrutka M4x20
  - 
  - Upevnenie kluky
```
````

### <font color='brown'> Zostava žeriava </font>

```{figure} ./model/0215_mini_zeriav/img/img_sc_02.png
:width: 350px

Zostava malého žeriavu (ver. 1.0).
```

````{subfigure} AB
:layout-sm: A|B
:gap: 2px
:subcaptions: below
:width: 700px

```{image} ./model/0215_mini_zeriav/img/diely_05.jpg
:alt: Detail kabíny a podpery ramena
:height: 200px
```

```{image} ./model/0215_mini_zeriav/img/diely_04.jpg
:alt: Detail navijaku
:height: 200px
```

Detaily konštrukcie.
````

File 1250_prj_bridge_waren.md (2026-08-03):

---
jupytext:
  formats: md:myst
  text_representation:
    extension: .md
    format_name: myst
    format_version: 0.13
    jupytext_version: 1.11.5
kernelspec:
  display_name: Python 3
  language: python
  name: python3
---
# <font color='navy'> Konštrukcie mostov  </font>

```{figure} ./img/banner.png
:width: 800px
:name: exam_001
```
Stavebné inžinierstvo pozná niekoľko základných konfigurácií priehradových mostných konštrukcií. S využitím štandardných ako aj modifikovaných dielov si môžete vytvoriť most podľa Vašich predstáv a preskúmať vlastnosti konštrukcie.

```{figure} ./model/0212_waren/img/mosty.gif
:width: 700px
:name: exam_005

Typy priehradových mostov.
```

## <font color='purple'> Návrh mostu typu Warren  </font>

Pre model priehradového mostu typu Warren potrebujeme okrem štandardných dielov z knižnice vygenerovať upravené komponenty, ktoré vyplývajú z geometrie konštrukcie. Most je možné zostaviť zo štandardných dielov, jediným špecifickým dielom je šikmá výztuha.

```{figure} ./model/0212_waren/img/most_05.png
:width: 700px
:name: exam_004

Model priehradového mostu s nosníkmi typu [Warren](https://en.wikipedia.org/wiki/Warren_truss) 
```

### <font color='brown'> Návrh modifikovaných dielov  </font>

Vzdialenosť otvorov pre šikmú výztuhu nie je celočíselným násobkom **BU**, 

$$
L=\sqrt{70^2 + 70^2} = 98.99
$$

a je približne o 1 mm kratšia ako je dĺžka štandardnej spojky.

```{figure} ./model/0212_waren/img/vypocet_view.png
:width: 350px
:name: exam_1250b

Dĺžka šikmej výztuhy (všetky miery v mm).
```

Pre spojenie dielov preto použijeme spojku so štrbinou, z dôvodu jednoduchosti a zámennosti použijeme štrbiny na oboch koncoch spojky. Z obrázku je zrejmý presah štrbiny nad montážnym otvorom.

```{figure} ./model/0212_waren/img/vypocet_zostava.png
:width: 330px
:name: exam_1250c

Zostava so šikmou výztuhou..
```

```{code-block} Python
:caption: Konštrukcia šikmej výztuhy.
from lib import *
b6 = Brace(11)
h2 = Hole_Slot(2, 3/4)
h3 = Hole_Slot(2, 3/4).BU_Tx(9)
b6.D([h2,h3])
b6.export_step('../parts/brace_B_11_07_02')  
```

```{code-cell} ipython3  
:tags: ["remove-cell"]

from lib import *
from lib.utils import *

b6 = Brace(11)
h2 = Hole_Slot(2, 3/4)
h3 = Hole_Slot(2, 3/4).BU_Tx(9)
b6.D([h2,h3])
convert_to_image(b6, './src/brace_b6')
```

```{figure} ./src/brace_b6.png
:width: 300px

 Šikmá výstuha
```

### <font color='brown'> Zostava a diely </font>

```{figure} ./model/0212_waren/img/zostava.png
:width: 500px
:name: exam_1250a

Zostava segmentu mostu.
```

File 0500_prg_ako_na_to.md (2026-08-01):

---
jupytext:
  formats: md:myst
  text_representation:
    extension: .md
    format_name: myst
    format_version: 0.13
    jupytext_version: 1.11.5
kernelspec:
  display_name: Python 3
  language: python
  name: python3
---
# <font color='navy'> Programovanie </font>

```{figure} ./img/banner.png
:width: 800px
:name: prg_100
```
Základným princípom stavebnice *STEMFIE-X* je možnosť vytvárania vlastných dielov stavebnice, ich modifikácie a úprav. Na rozdiel od klasických konštrukčných stavebníc nemá *STEMFIE-X* pevne stanovený rozsah komponentov a príslušenstva, šikovný konštruktér si môže nové diely stavebnice vytvárať podľa potreby.

Pri návrhu modelov a konštrukcií takto môže vzniknúť potreba použitia dielu, ktorý sa nenachádza v knižnici komponentov, alebo potrebujeme vytvoriť neštandardný diel ako je napríklad držiak motora, serva, senzora. Nové diely môžeme vytvárať pomocou skriptov v programovacom jazyku *Python* využitím knižnice *STEMFIE-X* pre tvorbu komponentov, komplikovanejšie komponenty môžeme vytvárať kombináciou pomocou logických operácií. Pokročilí uživatelia môžu pri tvorbe dielov využívať aj vlastnosti knižnice *CadQuery*, pomocou ktorej je knižnica *STEMFIE-X* naprogramovaná. 

## <font color='purple'> Parametre stavebnice </font>

Princíp stavebnice *STEMFIE-X* umožňuje tvorbu širokého spektra konštrukčných prvkov. Aby bola dodržaná vzájomná kompatibilita dielov, je vhodné pri návrhu dielov dodržať jednoduché základné pravidlá. 

Vlastnosti dielov stavebnice *STEMFIE-X* definuje základná jednotka **BU** (Basic Unit), priemer montážnych otvorov **HR_BASE** (Hole Radius) pre montážne prvky (skrutky a pod.) a otvory pre pohyblivé spoje, hiadele a osi **HR_AXIS**. Na rozdiel od kovových stavebníc, ktoré majú diely z plechu a pri ktorých sa neuvažuje s ich hrúbkou, musíme pri našich konštrukciách uvažovať s hrúbkou dielov. Rozmery dielov sú udávané v násobkoch alebo podieloch **BU**. 

 Štandardné parametre dielov sú definované ako

* štandardná veľkost jednotky **BU** je 10mm
* štandardný priemer montážnych otvorov **HR_BASE** je 4 mm
* priemer otvorov pre rotačné spoje, osi a hriadele **HR_AXIS** je 4.25 mm
* veľkost dielov **D** je celočíselná v násobkoch 1, 2 ... **BU** 
* hrúbka dielov **H** je v násobkoch 1, 1/2, 1/3, 1/4 **BU**

```{admonition} Úpravy štandardných parametrov
:class: tip

Pri vytváraní podkladov pre 3D tlač pomocou s využitím knižnice *Stemfie-X* možeme zmenou hodnôt premenných **BU**, **HR_BASE** a **HR_AXIS** upraviť vlastnosti a rozmery dielov stavebnice. Napríklad ak chceme pre spájanie dielov využiť skrutky, ktoré si v dieloch "vyrežú" vlastný závit, je vhodné hodnotu **HR_BASE** zmeniť na veľkosť 3.95mm. Skutočná veľkosť otvorov vo vytlačených dieloch závisí od použitého materiálu a parametrov tlače. 

```

## <font color='purple'>  Konštrukcia nového dielu </font>

Pri návrhu našej konštrukcie sme zistili, že potrebujeme spojku v tvare T o hrúbke 1/4 BU. Pri návrhu môžeme ako pomôcku na náčrty používať štvorčekový papier s rastrom 5mm (**BU/2**), na ktorom získame predstavu o skutočnej veľkosti dielov. 

```{figure} ./img/prg_navrh.jpg
:width: 350px

Náčrt dielu na štvorčekovom papieri.
```

Náš diel do stavebnice "vyrobíme" naprogramovaním v jazyku *Python* s použitím knižnice *STEMFIE-X* pre projektovanie dielov. K výrobe dielu potrebujeme 

* elementárne znalosti informatiky a programovania, najlepšie v *Pythone* (súbor, adresár, spustenie programu, základné syntaktické konštrukcie, práca s knižnicami)
* nainštalovaný editor *CQ-Editor* s knižnicou *CadQuery* a v pracovnom adresári rozbalenú knižnicu pre *Stemfie-X* podľa [návodu](./0900_instalacia.md) 
* nainštalované programy pre [prehliadanie](./0905_viewer.md) podkladov pre 3D tlač a generovanie dát (slicer) pre tlačiareň
* znalosť práce s 3D tlačiarňou 

## <font color='purple'>  Návrh dielu </font>

Pri návrhu dielu postupujeme podľa nasledujúcich bodov

* vytvoríme si pracovný adresár a rozbalíme do podadresári *./lib* [knižnicu](./lib/lib.zip) pre návrh dielov 
* spustíme program  *CQ-Editor*, vytvoríme nový súbor (*File -> New*) a **uložíme** (*File -> Save*) ho do pracovného adresára
* vytvoríme program pre návrh dielu

```{code-block} python
:caption: Vytvorenie T-spojky 

from lib import *            # import kniznice Stemfie-X
b1 = Brace(5)                # vytvorenie spojky o velkost 5BU v rovine XY
b2 = Brace(3).Rz().BU_Tx(2)  # vytvorenie spojky 3BU
                             # Rz()      - otocenie o 90 stupnov okolo osi Z
                             # BU_Tx(2)  - posun v smere osi X o dlzku 2BU      
b1 = b1.U([b2])              # U() union - zjednotenie (spojenie) objektov 
show_object(b1.obj)          # zobrazenie dielu v CQ-Editor
b1.export_step('part_b1')    # vygenerovanie podkladov pre tlac vo formate STEP
```

Program spustíme pomocou zelenej šípky v záhlaví editoru alebo klávesou F5. Osi súradnicovej sústavy sú zobrazené v pravom dolnom rohu okna prehliadača. Pre zobrazenie chybových hláseni pri preklade treba mať aktivovanú voľbu *Current tracebak* vo voľbe *View*.  

```{figure} ./img/prg_cq.png
:width: 600px

Návrh dielu v CQ-Editore.
```

%```{admonition} Zdrojové kódy
%:class: tip
%
%V tejto publikácii budeme zobrazovať zdrojové kódy príkladov bez príkazov pre import *Stemfie-X* knižníc *lib* a príkazov na export a zobrazenie objektov
%
%      b1 = Brace(5)                
%      b2 = Brace(3).Rz().BU_Tx(2)       
%      b1 = b1.U([b2])             
%      
%Príkazy na zobrazenie objektov sa líšia podľa použitého editora a príkazy na export objektov sa používajú v závislosti od kontextu príkladu. 
%```

## <font color='purple'>  Export podkladov pre tlač  </font>

Program vygeneruje príkazom *b1.export_step('part_b1')* podklady pre tlač vo formáte STEP. Tento formát je bezstratový, obsahuje vnútornú štruktúru objektu a vygenerované dáta je možné používať v kompatibilných CAD systémoch, napríklad [FreeCAD](https://www.freecad.org/). 

Podklady je možné vygenerovať aj vo formáte STL príkazom *b1.export_stl('part_b1')*, ktorý je tak isto možné použiť pre 3D tlač, formát STL je stratový, obsahuje len vonkajšie plochy objektu.

Exportované dáta môžeme prehliadať vo vhodnom prehliadači, napríklad [f3d](https://f3d.app/)

```{figure} ./img/part_b1.png
:width: 300px

Prehliadanie vygenerovaných dát v prehliadači *f3d*.
```

## <font color='purple'>  3D Tlač  </font>

Vytvorené dáta spracujeme programom pre generovani povelového kódu pre 3D tlačiareň (gcode). Presný postup závisí od použitej tlačiarne, na obrázku je spracovanie podkladov pre tlač pomocou programu [PrusaSlicer](https://www.prusa3d.com). 

```{figure} ./img/prg_slicer.png
:width: 600px

Generovanie dát pre 3D tlač.
```

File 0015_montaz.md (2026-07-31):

---
jupytext:
  formats: md:myst
  text_representation:
    extension: .md
    format_name: myst
    format_version: 0.13
    jupytext_version: 1.11.5
kernelspec:
  display_name: Python 3
  language: python
  name: python3
---

# <font color='navy'> Montážne prvky </font>

```{figure} ./img/banner.png
:width: 800px
```

Pre pevné nepohyblivé spoje dielov môžeme použiť bežné dostupné skrutky, nastavovacie skrutky, závitové tyče s rozmerom M4. Pre pohyblivé spoje, osi, hriadele môžeme použiť tyče, paličky s priemerom 4mm, podľa potreby a použitia kovové, plastové alebo aj drevené. 

## <font color='purple'> Pevné spoje </font>

### <font color='brown'> Skrutkové spoje </font>

Ako štandardné spojovacie prvky skrutkových spojov môžete použiť bežné kovové skrutky a matice **M4**, ktoré sú dostupné v každom železiarstve alebo špecializovanom obchode so spojovacím materiálom. Skrutky sú dostupné v rôznych dĺžkach, prevedeniach a povrchových úpravách, vhodné dĺžky skrutiek sú 5, 6, 8, 10, 15 a 20 mm (označenia M4x5, M4x6, M4x8, M4x10, M4x15, M4x20). 

Vhodné typy skrutiek sa vyrábajú pod normovaným označením

* DIN912  Šesťhranná skrutka s valcovou hlavou s vnútorným šesťhranom 
* DIN7984 Šesťhranná skrutka s nízkou hlavou s valcovou hlavou s vnútorným šesťhranom 
* DIN934  Šesťhranná matica 
* DIN439  Šesťhranná matica, nízky profil

```{figure} ./img/m4_912_screew.jpg
:width: 250px

Označenie skrutiek DIN912.
```

Pri nákupe väčšieho množstva môže byť cena veľmi prijateľná, závisí od prevedenia a povrchovej úpravy. Ak chcete konštrukcie používať vo vonkajšom prostredí, zvoľte pozinkované alebo nerezové prevedenie. Okrem kovových skrutiek môžete použiť aj plastové skrutky a matice z nylonu, ich cena je ale zvyčajne vyššia. Ako montážne náradie pre skrutky s vnútorným šesťhranom sú vhodné imbusové kľúče dostupné v sade alebo aj jednotlivo. 

Na spájanie tenkých prvkov (napríklad dve spojky s hrúbkou BU=1/4) je vhodné použiť skrutku s maticou, podobne ako v prípade kovových stavebníc. 

```{figure} ./img/asm_01.png
:width: 600px

Spájanie tenkých prvkov pomocou skrutky a matice.
```
Na spájanie hrubších dielov (BU = 1/2 a viac) môžeme využiť skutočnosť, že otvory v 3D tlačených prvkoch sú zvyčajne o niečo menšie ako stanovený priemer HR_BASE a skrutky si v nich vyrežú vlastný závit, nie je potrebné použiť maticu.

```{figure} ./img/asm_02.png
:width: 600px

Spájanie hrubších prvkov.
```

### <font color='brown'> Skryté spoje </font>

Ak hlavy štandardných skrutiek v niektorých spojoch z praktických alebo estetických dôvodov prekážajú, s trochou zručnosti je možné na spoje použiť nastavovacie skrutky. Dostupné sú v podobných dĺžkach ako štandardné skrutky, pre montáž budeme potrebovať imbusový kĺúč vhodnej veľkosti.

Vhodné typy nastavovacích skrutiek sa vyrábajú pod normovaným označením

* DIN 913 Nastavovacia skrutka s plochým hrotom
* DIN 916 Závitový kolík

```{figure} ./img/m4_913_cervik.jpg
:width: 250px

Označenie nastavovacích skrutiek DIN913.
```

```{figure} ./img/asm_04.png
:width: 600px

Použitie nastavovacích skrutiek.
```

### <font color='brown'> <b> Spojovací materiál </b></font>

Pre niektoré konštrukcie môžeme pre spájanie dielov využiť aj rôzne stĺpiky s vnútorným alebo vonkajším závitom M4. Tieto dostupné v rôznych dĺžkach a prevedeniach, kovové alebo plastové.

```{figure} ./img/stlpiky.png
:width: 600px

Použitie stlpikov.
```

## <font color='purple'> Pohyblivé spoje </font>

Pre pohyblivé spoje (osi kolies a kladiek, otočné spoje a podobne) môžeme využiť kovové alebo plastové hriadele s priemerom 4mm. Plastové paličky vhodného priemeru sú dostupné v kuchynských potrebách alebo v hobby-marketoch ako paličky pre zváranie plastov. Kovové hriadele rôznych v dĺžkach od 10 do 60mm sú dostupné ako nastavovacie kolíky v obchodoch so spojovacím materiálom.

Montážne otvory pre použitie hriadeľov je potrebné primerane zväčšiť, je vhodné si vopred skalibrovať 3D tlačiareň, pretože otvory vo vytlačených  dieloch majú zvyčajne menší priemer v závislosti od nastavených parametrov tlače a použitého materiálu. V prípad potreby je možné otvory pre hriadele a osi jemne upraviť ihlovým pilníkom.

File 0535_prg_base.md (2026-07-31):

---
jupytext:
  formats: md:myst
  text_representation:
    extension: .md
    format_name: myst
    format_version: 0.13
    jupytext_version: 1.11.5
kernelspec:
  display_name: Python 3
  language: python
  name: python3
---
# <font color='navy'> Bloky </font>

```{figure} ./img/banner.png
:width: 800px
:name: stmx_112
```

```{figure} ./img/image_base.png
:width: 800px
:name: stmx_110

```

Základnými blokmi stavebnice sú jednoduché tvary ako hranoly, valce, tyče. Používajú ako základ pre konštrukciu zložených dielov alebo ako dištančné prvky. Pomocou logických operácií (zjednotenie, prienik, rozdiel) môžeme z nich vytvátať komplikovanejšie objekty. Neobsahujú montážne otvory, tie je možné doplniť pomocou triedy `Hole` z knižnice. 

## <font color='purple'> Knižnica </font>

Knižnica základných komponentov s rozmermi zadávanými v **BU** jednotkách. Parameter **center** určuje, či komponent bude umiestnený v strede súradnicovej sústavy, čo je výhodné pri konštrukcii osovo symetrických dielov. 

    BU_Cube([x,y,z], center)                           # kocka / hranol
    BU_Cylinder(diameter, height, angle, hole, center) # valec
    BU_PolyLine([ [x1,y1], [x2,y2], ...], height)      # mnohouholník, extrudovaný
    BU_PolyRot([ [x1,y1], [x2,y2], ...], angle)        # mnohouholník, rotovaný
    BU_Cone(diam1, diam2, height, angle, center)       # kužel
    BU_Sphere(diameter, angle1, angle2, center)        # gula [ToDo]
    
    Parametre       Default   Popis 
    --------------------------------------------------------------
    x,y,z           1,1,1     rozmery 
    height          1/4       výška
    length          1         dĺžka 
    diameter        1         priemer
    hole            True      radiálny montážny otvor
    angle           360       uhol v stupňoch
    [xn,yn]                   súradnica bodu
    center          True      poloha v strede súradnicovej sústavy 
    
```{admonition} Základné bloky
:class: tip
Funkcie pre tvorbu základných blokov sú založené na zjednodušenom rozhraní k objektom z knižnice [CadQuery](https://cadquery.readthedocs.io). V prípade potreby konštrukcie komplikovanejších objektov na základe špeciálnych požiadaviek, napríklad skosené alebo zaoblené hrany, môžeme použiť priamo objekty a metódy knižnice *CadQuery*.   
```

### <font color='brown'> <b> Značenie dielov </b></font>

    base_t_p1_p2_p3_ ...                p1 ... pn  počet parametrov  
                                                   závisí od typu komponentu

    t  - typ komponentu                 pn - parameter, v BU jednotkách alebo uhle v stupnoch (ppp)
         B - cube                            01 =    1 BU            
         C - cylinder                           ...
         P - polyline                        10 =   10 BU
         R - polyrot                         12 =  1/2 BU 
         Q - sphere                          14 =  1/4 BU
         N - cone                            34 =  3/4 BU
         X - user defined                    ...

## <font color='purple'>  Príklady použitia </font>

```{code-block} Python
:caption: Jednoduché bloky
from lib import *
b1 = BU_Cube([1, 1.5, 2])     
b2 = BU_Cylinder(1,2, hole=True, center=False)  
b3 = BU_Cylinder(1.5,2, hole=False, center=False, angle=270) 
b4 = BU_Cone(0.25, 1.5, 2 )
```

```{code-cell} ipython3  
:tags: ["remove-cell"]

from lib import *
from lib.utils import *

bc  = BU_Cube([1, 1.5, 2])                                     # base_B_03_02_01  3x2x1 BU cube
by1 = BU_Cylinder(1,2, hole=True, center=False)                # base_C_01_01
by2 = BU_Cylinder(1.5,2, hole=False, center=False, angle=270)  # base_C_01_02_270
br  = BU_Cone(0.25, 1.5, 2 ).Rx(180).BU_Tz(-4)
bc.U([by1.BU_Tx(2), by2.BU_Tx(4.5),  br.BU_Tx(6)]  )
convert_to_image(bc, './src/img_0535a')
```

```{figure} ./src/img_0535a.png
:width: 450px

Jednoduché bloky.
```

```{code-block} Python
:caption: Operácie s blokmi
from lib import *
q = [ [0,0], [1,0], [1,1], [2,1], [2,0], [3,0], [3,2], [0,2], [0,0]]
b1 = BU_PolyLine(q, 1/2)
b2 = BU_PolyRot(q, 90)
```

```{code-cell} ipython3  
:tags: ["remove-cell"]

from lib import *
from lib.utils import *

q = [ [0,0], [1,0], [1,1], [2,1], [2,0], [3,0], [3,2], [0,2], [0,0]]
b1 = BU_PolyLine(q, 1/2)
b2 = BU_PolyRot(q, 90)
b1.U(b2.BU_Tx(4))
convert_to_image(b1, './src/img_0535b')
```

```{figure} ./src/img_0535b.png
:width: 350px

Extrudované a rotované bloky.
```

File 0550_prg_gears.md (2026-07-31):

---
jupytext:
  formats: md:myst
  text_representation:
    extension: .md
    format_name: myst
    format_version: 0.13
    jupytext_version: 1.11.5
kernelspec:
  display_name: Python 3
  language: python
  name: python3
---
# <font color='navy'> Ozubené kolesá  </font>

```{figure} ./img/banner.png
:width: 800px
:name: stmx_112
```

```{figure} ./img/gears_demo.png
:width: 600px

Ozubené kolesá
```

## <font color='purple'> Knižnica </font>

### <font color='brown'>  Značenie dielov </font>

## <font color='purple'> Príklady použitia </font>

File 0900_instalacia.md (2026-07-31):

---
jupytext:
  formats: md:myst
  text_representation:
    extension: .md
    format_name: myst
    format_version: 0.13
    jupytext_version: 1.11.5
kernelspec:
  display_name: Python 3
  language: python
  name: python3
---
# <font color='navy'> Inštalácia </font>

```{figure} ./img/banner.png
:width: 800px
:name: prg_125
```

Programové vybavenie stavebnice *Stemfie-X* umožňuje návrh a generovanie podkladov pre štandardné diely stavebnice, návrh vlastných dielov ako aj tvorbu jednoduchých zostáv. Programové vybavenie je založené na programovacom jazyku *Python* a pozostáva z nasledujúcich častí

* Knižnica *Stemfie-X* pre vytváranie dielov stavebnice 
* Knižnica *CadQuery* pre parametrické projektovanie založená na platforme *OpenCascade*
* Editor pre tvorbu programov s prehliadačom *CQ-Editor*
* Pomocné programy pre prehliadače generovaných dielov a zostáv (*f3d*, *FreeCAD*)
* Programy pre prípravu podkladov pre 3D tlač

## <font color='purple'>  Inštalácia pre Linux </font>

* Knižnica *Stemfie-X* je nadstavbou nad knižnicou *CadQuery* a je v dostupná v zdrojovom tvare v archíve [lib.zip](./lib/lib.zip). Knižnicu po rozbalení umiestnite do pracovného adresáru a pri vytváraní ju importujte do vašeho programu ako štandardnú knižnicu v Pythone. Knižnica je univerzálna pre všetky platformy. 

* Inštalácia platformy *CadQuery* je možná pomocou inštalátora *pip*. Inštalácia obsahuje všetky potrebné komponenty z *Open Cascade Technology (OCCT)* potrebné pre tvorbu konštrukcií v stavebnici. Dokumentácia ku *CadQuery* je dostupná [online](https://cadquery.readthedocs.io/en/latest/intro.html).

      sudo dnf install git
      pip install git+https://github.com/CadQuery/cadquery.git

* Pre platformu *CadQuery* bolo vytvorené jednoduché prostredie [CQ-Editor](https://github.com/CadQuery/CQ-editor), v ktorom je možné vytvárať, editovať a prehliadať diely stavebnice. Inštalačný skript je dostupný na [github-e](https://github.com/CadQuery/CQ-editor/releases/tag/nightly).

```{figure} ./img/cq_editor.png
:width: 650px
:name: prg_126
```

## <font color='purple'>  Inštalácia pre Windows </font>

TODO

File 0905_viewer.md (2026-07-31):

---
jupytext:
  formats: md:myst
  text_representation:
    extension: .md
    format_name: myst
    format_version: 0.13
    jupytext_version: 1.11.5
kernelspec:
  display_name: Python 3
  language: python
  name: python3
---
# <font color='navy'>  Vizualizácia  </font>

```{figure} ./img/banner.png
:width: 800px
:name: prg_125
```

## <font color='purple'> Prehliadač *F3D* </font>

Programč [F3D](https://f3d.app/) je univerzálny open-source prehliadač 3D dát podporujúci množstvo [formátov](https://f3d.app/docs/user/SUPPORTED_FORMATS). Prehliadač je možné používaž ako [webovú aplikáciu](https://f3d.app/viewer) alebo ako štandardnú aplikáciu. Inštalácia je možná zo stránok projektu alebo z repozitárov distribúcií, pre operačné systémy založené na distribúcii Ubuntu  

    sudo apt-get install f3d

Programu je možné používať ako prednastavený systémový prehliadač pre súbory *.step* a *.stl* alebo je ho možné spustiť z konzoly  

    f3d --watch --background-color 1,1,1 --grid=1 --axis=1 --grid-absolute --up +z  <file_name>.step

Parameter *--watch* umožní automatické obnovenie zobrazovaného objektu pri zmene zobrazovaného súboru. Pretože knižnica *Stemfie-X* vytvára primárne objekty v rovine XY, parameter *--up +z* definuje orientáciu mriežky a smer pohľadu. Ovládanie programu je jednoduché, on-screen help sa vyvolá klávesou `h`. 

Konfiguráciu programu je možné uložiť do konfiguračného súboru [*config.f3d*](./src/config.f3d) 

    [
      {
        "options": {
          "background-color": "1,1,1",
          "color": "0.39, 0.58, 0.92",
          "anti-aliasing": true,
          "watch":1,
          "axis": true,
          "grid": true,
          "up": "+z",
          "grid-absolute":true
        }
      }
    ]

Program spustíme s parametrom s cestou ku konfiguračnému súboru a menom zobrazovaného súboru

    f3d --config=./config.f3d <file_name>.step 
    
```{figure} ./img/f3d.png
:width: 500px

Vizualizácia súboru vo formáte STEP v programe *f3d*
```

%::::{grid} 4
%
%```{grid-item-card} Title
%:img-top: ./img/test_tetiva.png
%:class-card: sd-text-black
%:img-alt: my text
%
%Text
%```
%
%```{grid-item-card} Title
%:img-top: ./img/test_tetiva.png
%:class-card: sd-text-black
%:img-alt: my text
%
%Text
%```
%
%::::

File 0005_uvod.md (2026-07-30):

---
jupytext:
  formats: md:myst
  text_representation:
    extension: .md
    format_name: myst
    format_version: 0.13
    jupytext_version: 1.11.5
kernelspec:
  display_name: Python 3
  language: python
  name: python3
---
# <font color='navy'> Stemfie-X </font>

```{figure} ./img/banner.png
:width: 800px
```

`Stemfie-X` je konštrukčná stavebnica zameraná na polytechnické vzdelávanie s podporou praktického osvojenia si skúseností z moderných technológií v oblasti návrhu a konštrukcie mechatronických systémov, konštrukčných materiálov, elektroniky, programovania a riadenia. 

Stavebnica pokrýva aktivity od jednoduchého spoznávania elementárnych princípov konštrukcie a činnosti mechanických systémov, cez návrh vlastných konštrukcií s využitím katalógu hotových dielov a 3D tlače vybraných dielov až po návrh zložitejších sústav s podporou programovania, parametrického projektovania, elektronických prvkov a riadenia.

Základnými dielmi pre konštrukciu modelov sú spojky, bloky a platne s montážnymi otvormi vytlačené na 3D tlačiarni. Pre pokročilejšie konštrukcie je možné používať ozubené kolesá, kladky, držiaky motorov a serv. Pokročilí uživatelia si môžu upravovať a vytvárať vlastné diely pomocou konštruovania prostredníctvom programovania v jazyku Python. **Možnosť tvorby vlastných dielov** na základe vlastného návrhu **odlišuje** koncept stavebnice *Stemfie-X* od ostatných polytechnických stavebníc, kde je uživateľ odkázaný len na sadu dodávaných dielov bez možnosti ich úprav. 

```{figure} ./img/most.jpg
:width: 550px

Konštrukcia mostu z dielov Stemfie-X.
```

Koncept stavebnice je navrhnutý tak, aby bola dostupná každého mladého konštruktéra. Všetky podklady a konštrukčné návrhy sú open-source, pre tlač dielov je možné využiť bežne dostupnú 3D tlačiareň, pre tlač dielov je použitý recyklovateľný materiál PLA, ako spojovacie prvky sú použité skrutky a diely bežne dostupné v každom železiarstve. Pre riadenie elektronických častí je možné využiť dostupné moduly a diely z platformy Arduino. Pre zjednodušenie návrhu konštrukcií ako aj orientácie v rozmeroch dielov je v stavebnici použitá univerálna dĺžková jednotka **BU** (Basic Unit), ktorá reprezentuje vzdialenosť medzi montážnymi otvormi v dieloch stavebnice. 

## <font color='purple'> História </font>

`Stemfie-X` je odvodená z konštrukčnej stavebnice pre deti  [*STEMFIE*](https://stemfie.org/). Myšlienka stavebnice *STEMFIE* je založená na návrhu a následnej 3D tlači univerzálnych komponentov a spojovacích prvkov a konštrukcii vlastných modelov. Modely je možné zostavovať z návrhov hotových sád dielov, ktoré sa vytlačia na 3D tlačiarni, na návrh a konštrukciu vlastných modelov je možné použiť grafické programy a konštrukčné CAD systémy ako FreeCAD, Blender a Tinkercad.

```{figure} ./img/stemfie.png
:width: 800px

WWW stránky stavebnice [*STEMFIE*](https://stemfie.org/).
```

Stavebnica *Stemfie-X* využíva základné princípy projektu *STEMFIE* s úpravami pre použitie ako platforma pre vytváranie zložitejších štruktúr a modelov s použitím mechanických a elektronických prvkov - motorov, servopohonov, elektronických obvodov a riadenia mikrokontrolérmi. Stavebnica je primárne určená pre polytechnickú výučbu na základných a stredných školách a prvých semestrov vysokých škôl pri výučbe predmetov z oblasti programovania, parametrického modelovania, CAD systémov, konštrukcií strojov a mechanizmov. 

Základným rozdielom medzi *Stemfie-X* a *STEMFIE* je veľkosť základnej jednotky **BU**, ktorá určuje vzdialenosti medzi montážnymi otvormi, pôvodná veľkosť 12.5mm v *STEMFIE* je upravená na veľkosť 10 mm a montážne otvory majú priemer 4 mm. Tieto modifikácie umožňujú použiť ako spojovací materiál štandardné skrutky M4 a diely stavebnice sú rozmerovo kompatibilné s kovovými dielmi stavebníc *Meccano*, *Merkur*, *eitech* a podobnými.

Základnými prvkami stavebnice sú spojky a bloky, ktoré je možné modifikovať v násobkoch **BU**, rotačné diely tvoria kladky a kolesá, pre pokročílé konštrukcie je možné využiť ozubené kolesá a pomocné prvky pre montáž motorov, serv a senzorov.

```{figure} ./img/demo_02.png
:width: 350px

Ukážka základných dielov stavebnice Stemfie-X.
```

## <font color='purple'> Použitie </font>

Stavebnica *Stemfie-X* je navrhnutá pre použitie v niekoľkých úrovniach

* jednoduchá stavebnica pre menšie deti z vopred pripravených dielov 3D tlačou. Cieľom je získanie základných zručností pri spájaní dielov skrutkami použitím bežného náradia a získanie elementárnych poznatkov o základných mechanických sústavách (kladka, navijak, páka ...). Predpokladá sa asistencia učiteľa alebo rodiča.

* stavebnica modelov na základe pripravených konštrukčných pokladov pre 3D tlač. Cieľom je získanie zručností potrebných pre tlač dielov, prácu s 3D tlačiarňou a použitými materiálmi. 

* tvorba vlastných modelov zostavených z katalógu dielov s možným rozšírením pre generovanie dielov pomocou software. Cieľom je získanie zručností pri návrhu vlastných konštrukcií a prácou s CAD systémami (FreeCAD ...) pri overovaní si vytvorenej konštrukcie pred tlačou jej dielov. 

* konštrukcia modelov podľa vlastného návrhu s parametrickým projektovaním špeciálnych dielov v programovacom jazyku Python a návrhového systému OpenCascade  

* doplnenie vlastných modelov elektromechanické prvky, senzory a aktuátory s riadením pomocou modulov Arduina alebo podobnej platformy

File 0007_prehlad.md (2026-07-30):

---
jupytext:
  formats: md:myst
  text_representation:
    extension: .md
    format_name: myst
    format_version: 0.13
    jupytext_version: 1.11.5
kernelspec:
  display_name: Python 3
  language: python
  name: python3
---

# <font color='navy'> Konštrukčné prvky </font>

```{figure} ./img/banner.png
:width: 800px
:name: stmx_33
```

Stavebnica *STEMFIE-X* obsahuje základné typy dielov (spojky, nosníky, kladky, ozubené kolesá ...), ktoré je možné v závislosti od účelu použitia využívať niekoľkými spôsobmi:

* Pre oboznámenie sa zo stavebnicou sú pripravené zostavy dielov pre konštrukciu jednoduchých modelov, diely sú v podobe súborov pripravených pre 3D tlač. Po vytlačení dielov je možné model zostaviť s použitím spojovacieho materiálu (skrutiek, matíc ..) a bežného náradia

* Pre tvorbu vlastných konštrukcií sú vytvorené katalógy dielov vo formáte *.step* a *.stl* pripravených pre 3D tlač. Výber dielov, ich počet a farebné prevedenie pri 3D tlači si definuje konštruktér, vlastné konštrukcie je možné navrhovať jednoducho na papieri pomocou výberu z katalogových dielov alebo pri pokročilých konštruktéroch aj elektronicky vo vhodnom CAD programe, napríklad FreeCAD. 

* Pre pokročilých uživateľov znalých základov programovania je stavebnica dostupná vo forme knižnice pre programovací jazyk *Python*, v ktorom je možné modifikovať alebo vytvárať vlastné verzie dielov stavebnice. Taktiež je možné s využitím zaákaldných metód parametrického projektovania vytvárať špecializované diely pre integráciu motorov, serv, senzorov a elektronických modulov do stavebnice. 

Rozmery všetkých dielov sú udávané v jednotkách **BU** (**B**asic **U**nit, 1BU = 10mm). Pre jednoduchšiu orientáciu v typoch dielov bolo zavedené pomenovanie dielov, ktoré popisuje ich základné vlastnosti, napríklad *brace_B_10* je jednoduchá spojka o obsahujúca 10 montážnych otvorov. 

## <font color='purple'> Spojky  </font>

[Spojky (Brace)](0520_prg_brace) sú základným typom dielov stavebnice, slúžia na spájanie častí konštrukcie, ako nosníkov a podpier. V závislosti od účelu použitia môžu mať rôzny tvar, hrúbku a počet montážnych otvorov. V niektorých prípadoch môžu byť dva lebo aj viacej otvorov nahradených montážnou štrbinou, táto má význam pri požiadavke spájania dielov mimo štandardnej polohy montážneho otvoru. Rovnako môžeme štrbinu využiť aj pri tvorbe lineárnych posuvných mechanizmov.  

```{figure} ./img/image_brace.png
:width: 600px

Rôzne prevedenia spojok.
```

## <font color='purple'> Nosníky  </font>

[Nosníky (Beams)](0525_prg_beam) slúžia na konštrukciu nosných prvkov konštrukcií, základových platní a konštrukčných prvkov tam, kde sa vyžaduje zvýšená pevnosť, tuhosť alebo nosnosť. Okrem rozmerov nosníkov je možné modifikovať aj formu umiestnenia montážnych otvorov, napríklad len v smere vybranej osi. 

```{figure} ./img/image_block.png
:width: 600px

Rôzne prevedenia blokov.
```

## <font color='purple'>  Kladky </font>

[Kladky](0540_prg_pulley) a držiaky kladiek slúžia na konštrukciu jednoduchých strojov, lanových prevodov a  kladkostrojov.

```{figure} ./img/image_pulley.png
:width: 600px

Kladky a držiaky kladiek.
```

## <font color='purple'> Ozubené kolesá  </font>

Ozubené kolesá sú základom pre konštrukciu prevodoviek k motorom a servám. 

```{figure} ./img/gears_demo.png
:width: 600px

Ozubené kolesá
```

## <font color='purple'>  Základné bloky  </font>

[Základné bloky](0535_prg_base) sú podkladom pre konštrukciu vlastných neštandardných prvkov stavebnice.

```{figure} ./img/image_base.png
:width: 600px

Základné bloky
```

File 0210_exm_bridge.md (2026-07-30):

---
jupytext:
  formats: md:myst
  text_representation:
    extension: .md
    format_name: myst
    format_version: 0.13
    jupytext_version: 1.11.5
kernelspec:
  display_name: Python 3
  language: python
  name: python3
---
# <font color='navy'> Priehradový most  </font>

```{figure} ./img/banner.png
:width: 800px
:name: exam_001
```
Model priehradového mostu patrí medzi jednoduché statické konštrukcie pre začiatočníkov. Model mostu je zameraný na získanie elementárnych zručností pri používaní náradia, spojovacieho materiálu a správneho postupu montáže. Výsledný model zároveň intuitívne prezentuje elementárne poznatky zo statiky, kde je zrejmé, že nosnosť poskladaného mosta je väčšia ako jednoduchej lávky. 

Model mostu je zostavený zo štandardných dielov stavebnice bez dodatočných modifikácií a úprav dielov. 

```{figure} ./model/0210_most/img/most_03.png
:width: 700px
:name: exam_002

Model jednoduchého priehradového cestného mostu
```

## <font color='purple'> Montáž </font>

Postup montáže jedného segmentu mostu je zrejmý z nasledujúceho obrázku. Veľkosť mostu môžete upraviť pridávaním segmentov mostu. Pre montáž sú použité štandardné skrutky M4x6. V prípade potreby si môžete parametre modelu (napríklad šírku mostu) upraviť vygenerovaním upravených dielov pomocou programom s využitím knižnice komponentov.  

```{figure} ./model/0210_most/img/most_07.png
:width: 300px
:name: exam_021

Postup montáže časti segmentu mostu.
```

## <font color='purple'> Diely </font>

Farebné prevedenie dielov je orientačné, pre konštrukciu si môžete zvoliť vlastné farebné prevednie. 

````{dropdown} Zoznam dielov priehradového mostu.

```{list-table}
:header-rows: 1

* - Počet
  - Popis
  - Farba
  - Súbor (step)
* - 3
  - Mostovka
  - bledomodrá
  - [block_U_10_05_14](./model/0210_most/parts/block_U_10_05_14_12.step)
* - 2
  - Pilier
  - hnedá
  - [block_H_05_05_14_12_02_02](./model/0210_most/parts/block_H_05_05_14_12_02_02.step)
* - 8
  - Spojka mostovky
  - oranžová
  - [brace_B_04_14](./model/0210_most/parts/brace_B_04_14.step)
* - 12
  - Diely nosníka
  - červená
  - [brace_B_09_14](./model/0210_most/parts/brace_B_09_14.step)
* - 4
  - Diely nosníka
  - oranžová
  - [brace_B_11_14](./model/0210_most/parts/brace_B_11_14.step)
* - 3
  - Spojky nosníkov
  - šedá
  - [block_U_02_05_14_12](./model/0210_most/parts/block_U_02_05_14_12.step)
* - 36
  - Skrutka M4x6
  - šedá
  - 
```
````

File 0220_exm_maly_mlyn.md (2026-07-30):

---
jupytext:
  formats: md:myst
  text_representation:
    extension: .md
    format_name: myst
    format_version: 0.13
    jupytext_version: 1.11.5
kernelspec:
  display_name: Python 3
  language: python
  name: python3
---

# <font color='navy'> Veterný mlyn </font>

```{figure} ./img/banner.png
:width: 800px
:name: exam_001
```
Veterný mlyn je jednoduchý kinematický model, ktorého súčasťou je jednoduchý kladkostroj. 

```{figure} ./model/0220_maly_mlyn/img/small_windmill.png
:width: 400px

```

## <font color='purple'> Montáž </font>

## <font color='purple'> Diely </font>

````{dropdown} Diely modelu

```{list-table}
:header-rows: 1

* - Počet
  - Popis
  - Farba
  - Súbor (step)
* - 4
  - Spojka, nosník
  - červená
  - [brace_B_10](./model/0220_maly_mlyn/parts/brace_B_10.step)
* - 1
  - Základňa
  - modrá
  - [block_U_10_05](./model/0220_maly_mlyn/parts/block_U_10_05.step)
* - 1
  - Oblúková spojka
  - červená
  - [brace_A_03_14_06_112](./model/0220_maly_mlyn/parts/brace_A_03_14_06_112.step)
* - 4
  - Spojka, vrtula
  - oranžová
  - [brace_B_05](./model/0220_maly_mlyn/parts/brace_B_05.step)
* - 2
  - Kladka
  - zelená
  - [pull_B_12](./model/0220_maly_mlyn/parts/pull_B_12.step)
* - 1
  - Koleso
  - zelená
  - [wheel_B_12_12](./model/0220_maly_mlyn/parts/wheel_B_12_12.step)
* - 1
  - Rúčka
  - zelená
  - [base_C_01_02](./model/0220_maly_mlyn/parts/base_C_01_02.step)
* - 12
  - Skrutka M4x5
  - šedá
  - 
* - 1
  - Skrutka M4x25
  - šedá
  - 
* - 2
  - Hriadel D4 x 70mm
  - šedá
  -
```

````

```{figure} ./model/0220_maly_mlyn/img/windmill_assembly.jpg
:width: 250px

Konštrukcia.
```

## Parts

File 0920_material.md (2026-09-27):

---
jupytext:
  formats: md:myst
  text_representation:
    extension: .md
    format_name: myst
    format_version: 0.13
    jupytext_version: 1.11.5
kernelspec:
  display_name: Python 3
  language: python
  name: python3
---
# <font color='navy'>  Konštrukčný materiál </font>

Stavebnica *Stemfie-X* je navrhnutá pre použitie štandardného spojovacieho materiálu (skrutiek, matíc) bežne dostupného v železiarstvách alebo špecializovaných obchodoch. Pre záujmové krúžky je cenovo výtrazne výhodnejšie nakupovať celé balenia vo veľkobchodnej sieti, kde je zvyčajne dostupný aj širší sortiment materiálu.

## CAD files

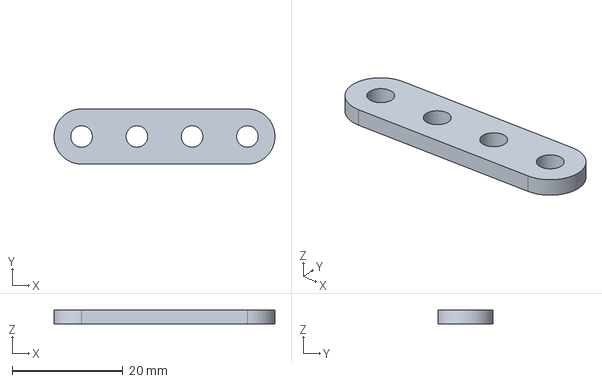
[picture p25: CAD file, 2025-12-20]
model/0210_most/parts/brace_B_04_14.step
40.0 x 10.0 x 2.50 mm

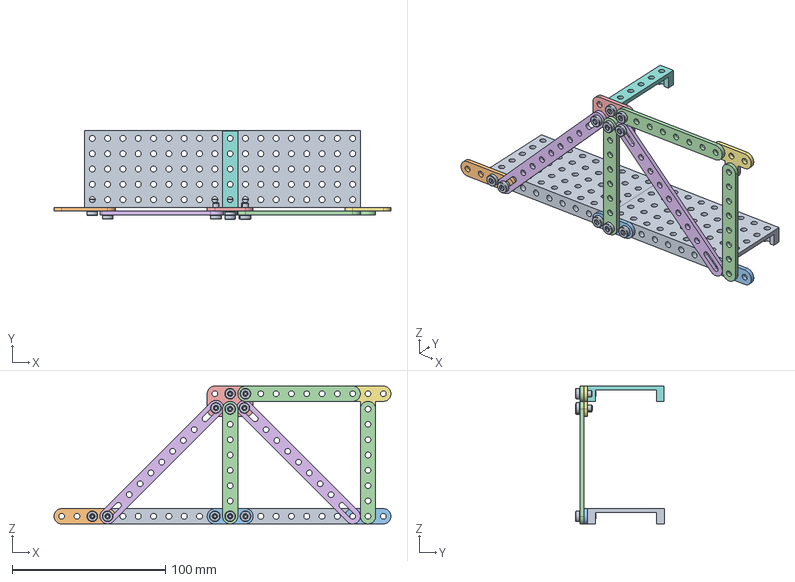
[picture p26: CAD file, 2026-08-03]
model/0212_waren/freecad/zostava.FCStd
220.0 x 57.8 x 90.0 mm
zakldna_9_BU x 2
spojka_4_BU
spojka_3_BU x 2
spojka_8_BU x 3
brace_P
spojka_11_BU x 2
brace_T
horny_nosnik
M4x8-Screw x 10

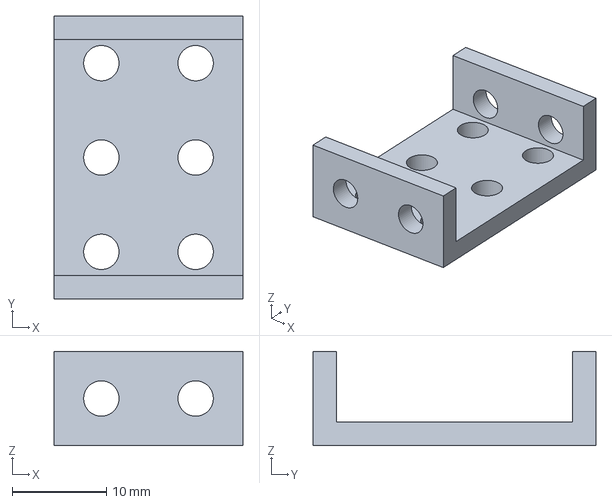
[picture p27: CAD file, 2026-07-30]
model/0215_mini_zeriav/parts/block_U_02_03.step
20.0 x 30.0 x 10.0 mm

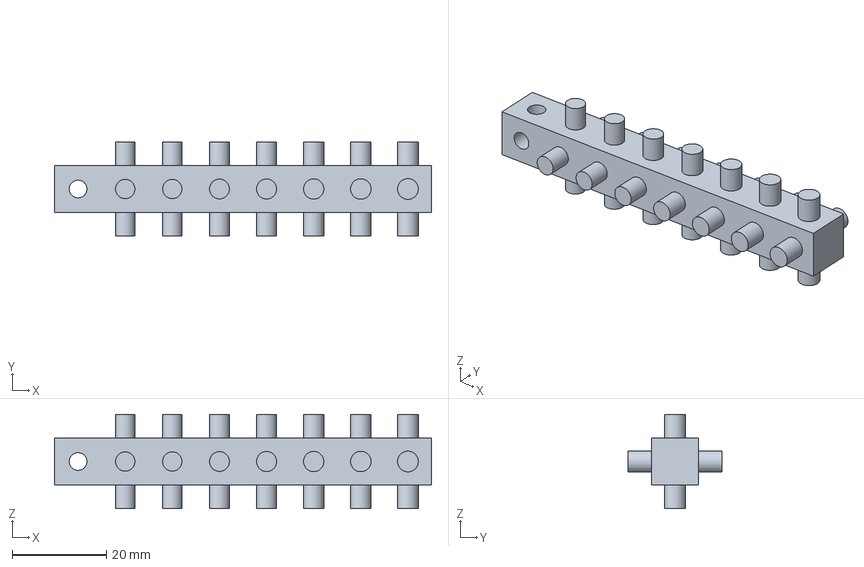
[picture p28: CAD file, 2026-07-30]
model/0215_mini_zeriav/py/bb_test.step
80.0 x 20.0 x 20.0 mm

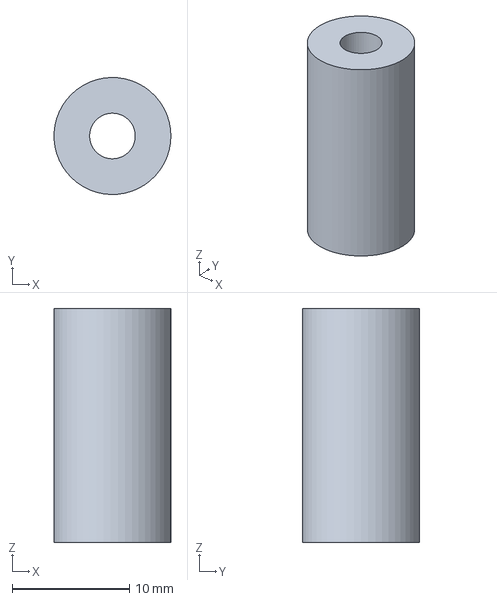
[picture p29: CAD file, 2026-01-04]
model/0220_maly_mlyn/parts/base_C_01_02.step
9.99 x 10.00 x 20.0 mm

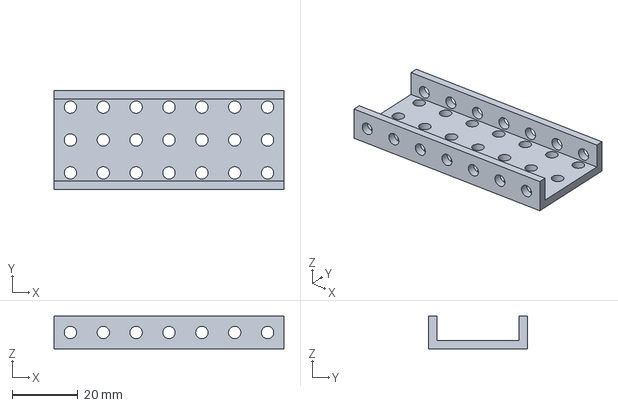
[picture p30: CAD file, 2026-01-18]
model/0225_bobcat/parts/block_U_07_03.step
70.0 x 30.0 x 10.0 mm

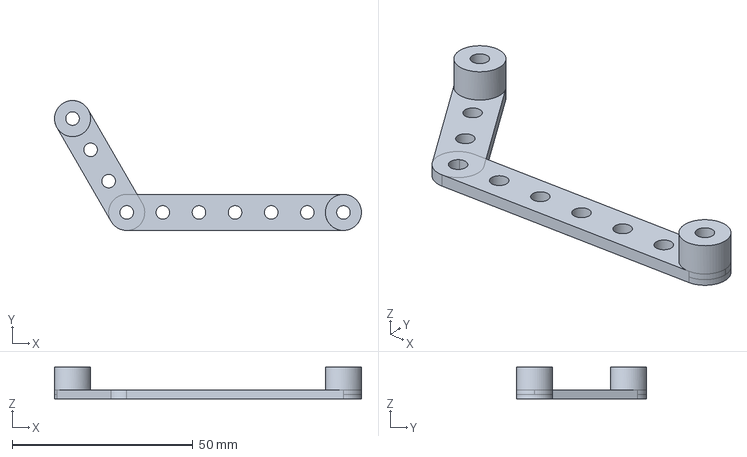
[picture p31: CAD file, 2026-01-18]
model/0225_bobcat_v02/parts/user_H_07_04_L.step
85.0 x 36.0 x 8.75 mm

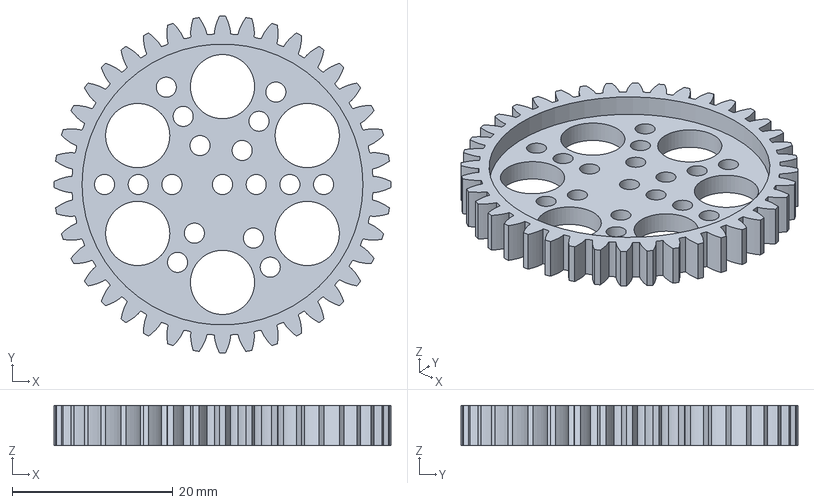
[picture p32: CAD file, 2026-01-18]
model/1020_spirograf/parts/sp_gear_40.step
42.0 x 42.0 x 5.00 mm

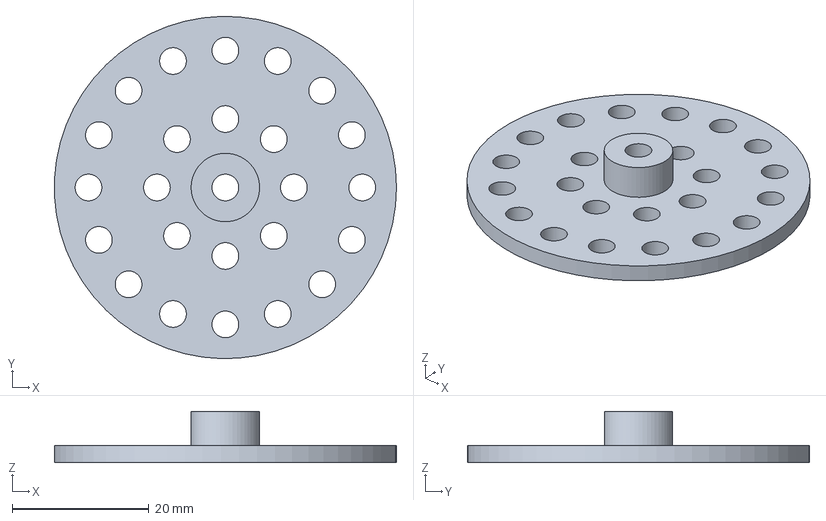
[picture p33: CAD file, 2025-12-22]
src/wheel_02_14_12.step
50.0 x 50.0 x 7.50 mm

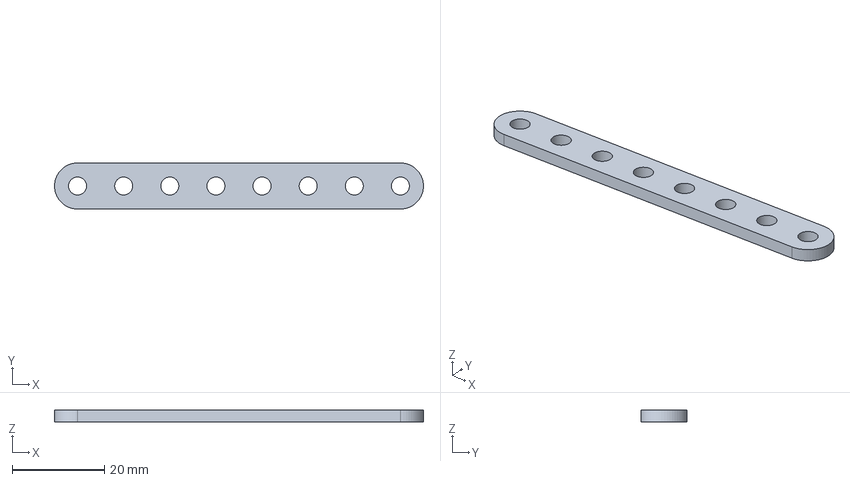
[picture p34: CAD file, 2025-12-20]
model/0210_most/parts/brace_B_08_14.step
80.0 x 10.0 x 2.50 mm

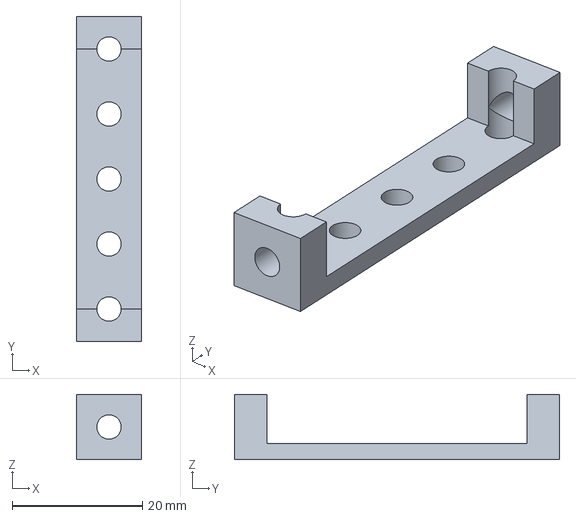
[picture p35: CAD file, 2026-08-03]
model/0212_waren/parts/block_U_01_05_14_12.step
10.0 x 50.0 x 10.0 mm

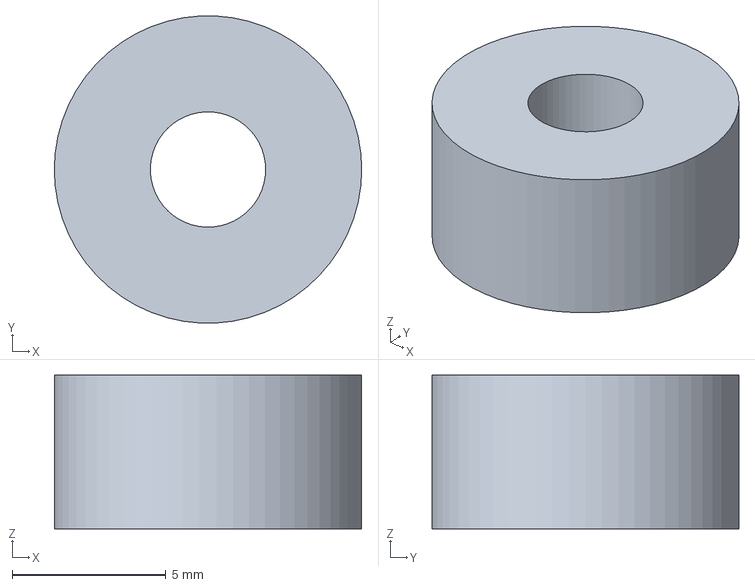
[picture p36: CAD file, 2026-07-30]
model/0215_mini_zeriav/parts/brace_B_01_12.step
10.0 x 9.99 x 5.00 mm

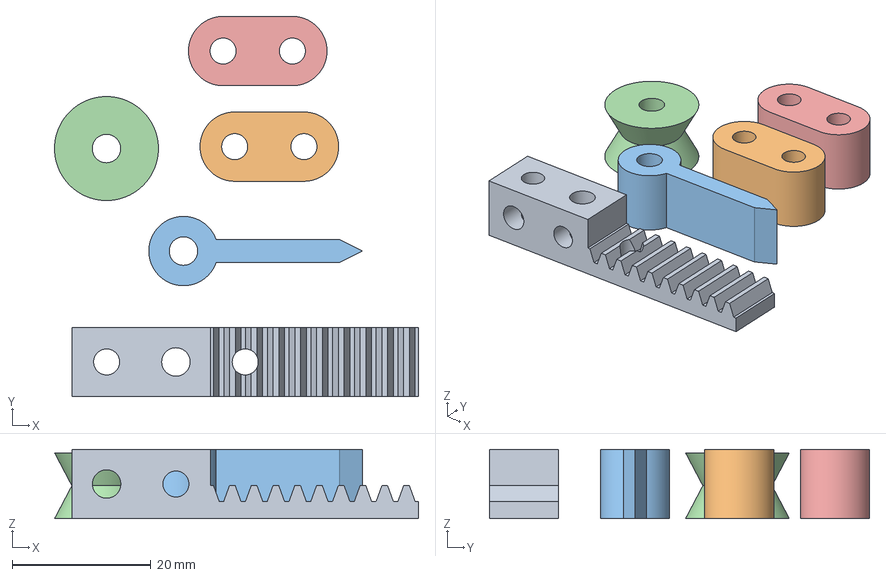
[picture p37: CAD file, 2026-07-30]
model/0215_mini_zeriav/py/hole_test.3mf
52.5 x 54.9 x 10.0 mm
rack_2
brace_B_02_01 x 2
podpera
pulley_A_15

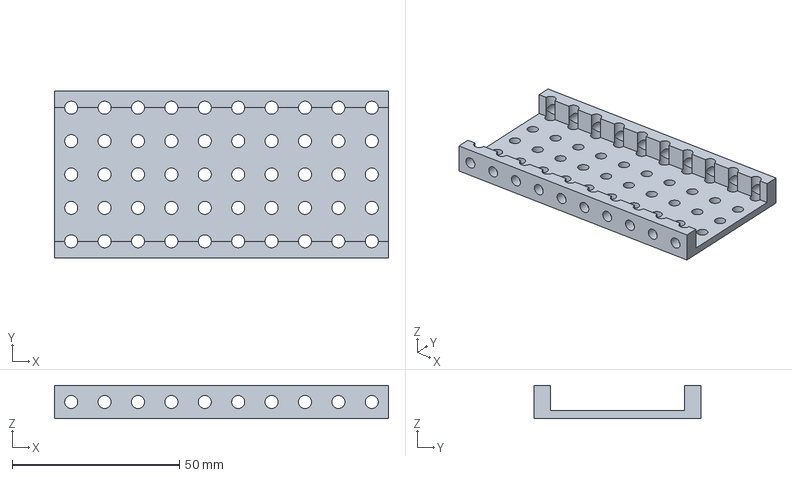
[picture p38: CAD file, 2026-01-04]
model/0220_maly_mlyn/parts/block_U_10_05.step
100.0 x 50.0 x 10.0 mm

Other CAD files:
model/0215_mini_zeriav/parts/assembly.FCStd
model/0212_waren/parts/brace_B_04_14.step
model/0212_waren/freecad/vypocet.FCStd
model/0225_bobcat/parts/user_P_03_24.step
model/0210_most/parts/block_U_02_05_14_12.step
model/0210_most/parts/brace_B_09_14.step
model/0210_most/parts/brace_B_11_14.step
model/0210_most/parts/brace_P_03_02_14.step
model/0212_waren/parts/block_H_05_05_14_12_02_02.step
model/0212_waren/parts/block_U_09_05_14_12.step
model/0212_waren/parts/block_U_10_05_14_12.step
model/0212_waren/parts/brace_B_03_14.step
model/0212_waren/parts/brace_B_08_14.step
model/0212_waren/parts/brace_B_11_07_02.step
model/0212_waren/parts/brace_P_03_02_14.step
model/0212_waren/parts/brace_T_03_02.step
model/0215_mini_zeriav/img/old/parts/base_C_01_01.step
model/0215_mini_zeriav/img/old/parts/base_C_01_12.step
model/0215_mini_zeriav/img/old/parts/base_C_01_15.step
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

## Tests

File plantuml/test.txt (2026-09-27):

  @startmindmap
  * Debian
  ** Ubuntu
  *** Linux Mint
  *** Kubuntu
  *** Lubuntu
  *** KDE Neon
  ** LMDE
  ** SolydXK
  ** SteamOS
  ** Raspbian with a very long name
  *** <s>Raspmbc</s> => OSMC
  *** <s>Raspyfi</s> => Volumio
  @endmindmap

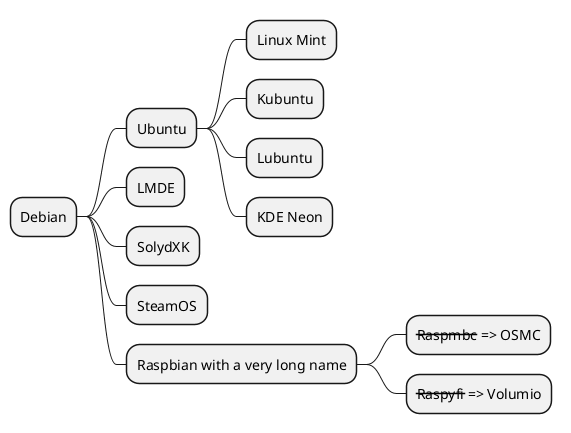
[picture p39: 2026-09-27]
plantuml/test.png

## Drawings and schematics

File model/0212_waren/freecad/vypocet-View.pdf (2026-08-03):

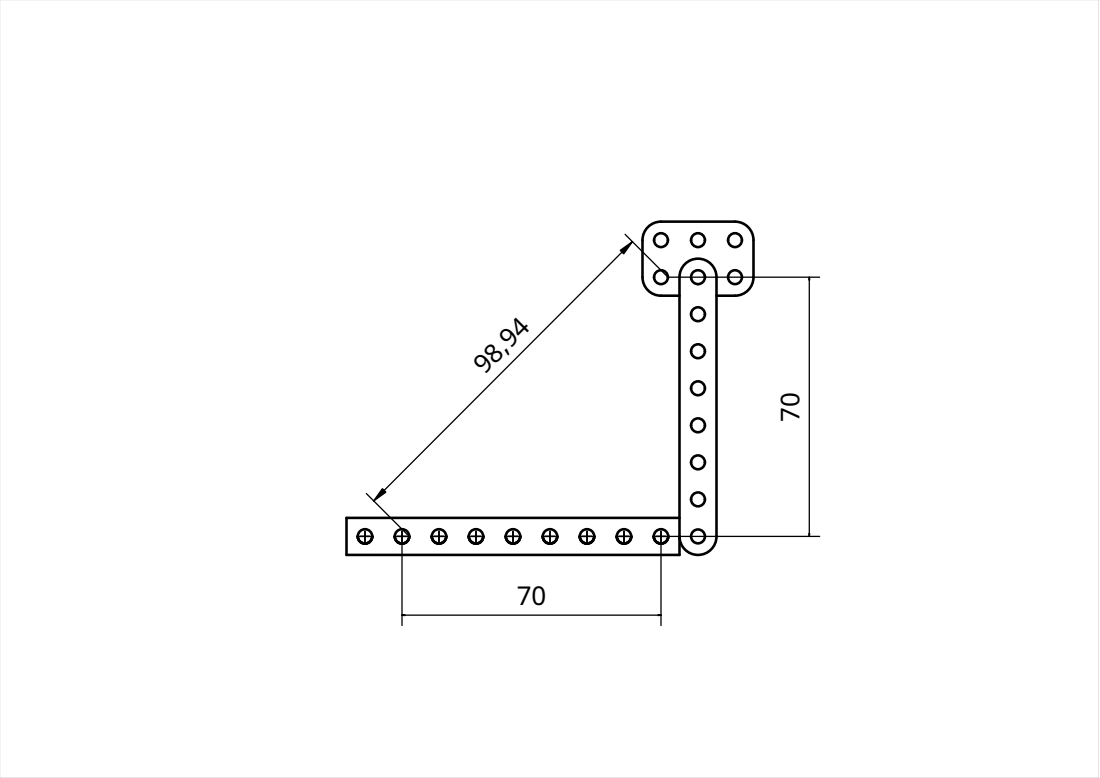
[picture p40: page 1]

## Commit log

2025-12-20 Editácia, doplnenie
    [block_H_05_05_14_12_02_02.step, block_U_01_05_14_12.step, block_U_02_05_14_12.step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]
2025-12-21 Doplnenia kapitol
    [wheel_02_14_12.step]
2025-12-22 Doplnenia, upravy
    [config.f3d, wheel_02_14_12.step]
2025-12-23 Doplneny navod k f3d
    [b1.step, b2.step, b3.step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]
2025-12-29 Doplnené a upravené kladky + zdrojové kódy
    [base_C_01_01.step, base_C_01_12.step, block_B_03.step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]
2026-01-02 Malý žeriav, návrh a konštrukcia
    [base_C_01_01.step, base_C_01_12.step, base_C_01_15.step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]
2026-01-03 Doplnena kapitola Projekty. Vytvorený projekt Spirograf.
    [sp_base_90.step, sp_gear_40.step, sp_gear_50.step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]
2026-01-04 Doplneny maly mlyn
    [base_C_01_02.step, block_U_10_05.step, brace_A_03_14_06_112.step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]
2026-01-18 Doplnenia a upravy
    [base_C_01_01.step, base_C_01_12.step, base_C_01_15.step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]
2026-07-30 Doplnenia a upravy modelov. Zmena obsahu.
    [assembly.FCStd, axis_15.step, axis_3.step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]
2026-07-31 Doplnenia a upravy textov, zmena formatovania kapitol, doplnenie obsahu.
    [comp_C_hook_block_02.step]
2026-08-03 Doplenenie - warren
    [block_H_05_05_14_12_02_02.step, block_U_01_05_14_12.step, block_U_09_05_14_12.step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]
